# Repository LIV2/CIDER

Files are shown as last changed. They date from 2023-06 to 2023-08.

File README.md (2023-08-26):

# CDTV IDE + RAM
IDE + 11.37 Megabyte Fast RAM + Dual Kickstart flash for the CDTV

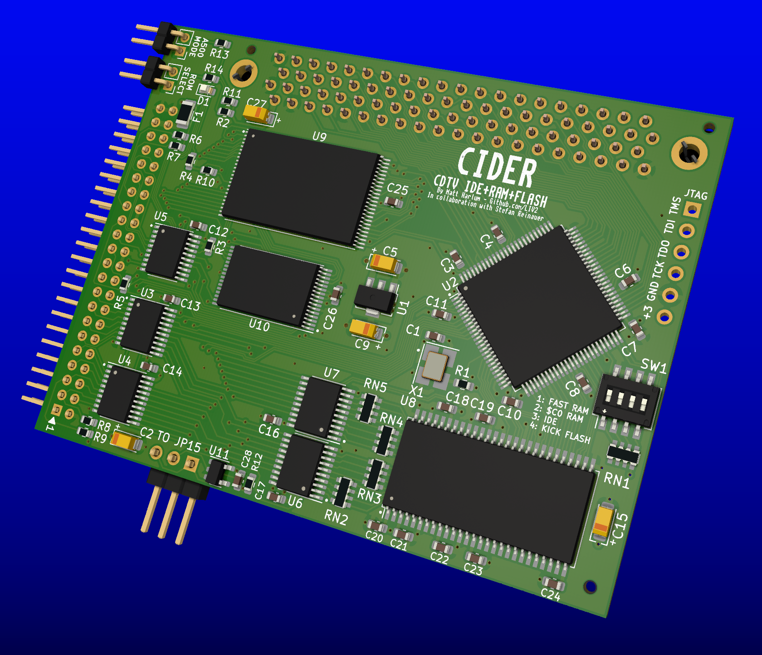
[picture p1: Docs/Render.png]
PCB


## Features

- Plugs in to the Diagnostic port
- Autoboot IDE, Kick 1.3 compatible Open Source driver [lide.device](https://github.com/LIV2/lide.device)
- 11.37MB Fast RAM - 1.5MB $C0/Ranger + 8MB Fast + 1.87 Bonus ($A00000)
- Dual Kickstart Flash ROM with Extended ROM, programmable in-system

## Table of contents
1. [Compatibility](#compatibility)
2. [Quick start](#quick-start)
3. [Switch settings](#switch-settings)
    * [DIP Switches](#dip-switches)
    * [JP15](#jp15)
4. [Programming](#programming)
5. [Software](#software)
6. [Common issues](#common-issues)
7. [Ordering pcbs](#ordering-pcbs)
    * [PCB Order details](#pcb-order-details)
    * [PCB Assembly](#pcb-assembly)
    * [Bill of materials](#bill-of-materials)
8. [Pictures](#pictures)
9. [Acknowledgements](#acknowledgements)
10. [License](#license)

## Compatibility

Compatible with kickstart 1.3 and up.

## Quick start
* Remove the power cord from your CDTV
* Ensure the kick flash switch is turned off before using for the first time, all other dip-switches may be enabled if you wish
* Plug into the diag port in your CDTV
* Connect jumper-wire from CDTV JP15 and "To JP15" header, or remove the jumper from the CDTV's JP15 header
* Boot from the CIDER-IDE-Update.adf [here](https://github.com/LIV2/CIDER-Software/releases) to install the IDE ROM
* Download the software tools from the [CIDER-Software](https://github.com/LIV2/cider-software/releases) release page
* Consult the software [documentation](https://github.com/LIV2/CIDER-Software/blob/main/README.md)

## Switch settings
* A500 Mode: Disables the CDTV extended rom
* ROM Select: Selects the second bank of the Kickstart Flash when closed

### DIP Switches
1. Fast RAM enable
2. Ranger / $C0 RAM enable
3. IDE enable
4. Kick flash enable

### JP15
CIDER needs to disable the CDTV's own extended roms when in A500 mode, or when CIDER's Kick flash is enabled so that it can take over this function  
If you don't have a cable to connect this, you can simply remove the JP15 jumper (but the ext rom will then be disabled even if kick flash is switched off)

## Programming

Program the CPLD using this [jed file](https://github.com/LIV2/CIDER/raw/main/Binary/CIDER.jed) - You can find instructions on how to do that [here](https://linuxjedi.co.uk/2020/12/01/programming-xilinx-jtag-from-a-raspberry-pi/)

IDE ROM can be programmed by booting from the latest CIDER-IDE-Update.adf [here](https://github.com/LIV2/CIDER-Software/releases).

## Software

Various software tools for CIDER are available in the [CIDER-Software](https://github.com/LIV2/CIDER-Software) repository, you can find disk images and .lha files under the Releases section.

## Common issues

* **CDTV doesn't boot from IDE:** The original CDTV bootstrap does not boot from hard disks by default, only the builtin scsi.device, floppy or cdrom.  
To boot from the HDD I recommend making use of the 2.35 Extended rom from [CDTV Land](https://cdtvland.com/os235/)

## Ordering PCBs

Download the latest Gerbers.zip from the latest release listed on the right-hand side of this page.

Also included in the release are the placement and bom files needed for JLCPCB's assembly service

### PCB Order details
This PCB has been designed to JLCPCB's 4-layer capabilities so I recommend ordering from them

* Layers: 4
* Surface finish: ENIG
* Remove Order Number: Specify a location

### PCB Assembly
The release files include the relevant BOM and CPL files for JLCPCB's Assembly service  
You can use the following options:  
* PCBA Type: Economic
* Assembly side: Top side
* Tooling Holes: Added by Customer
* Confirm Parts Placement: Yes (I recommend checking that all ICs have pin 1 in the correct location etc)

### Bill of materials
|References|Qty|Value|Footprint|Link|Notes|
|---|---|-----|---|----|-----|
|CN1|1|CDTV Connector|KEL 8801-080-170S-F| |Contact KEL to order|
|C1,C3,C4,C6,C7,C8,C10,C11-14,C16-26,C28|23|0.1uF Ceramic|0603|[Mouser](https://www.mouser.com/ProductDetail/80-C603C104K5RAC3121)| |
|C2,C5,C27|3|47uF Tantalum|EIA-3216 KEMET A|[Mouser](https://www.mouser.com/ProductDetail/80-T490A476M10ATE1K)| |
|C9,C15|3|10uF Tantalum|EIA-3216 KEMET A|[Mouser](https://www.mouser.com/ProductDetail/581-TAJA106K016R)| |
|R2,R3,R5-12|10|10K|0603|[Mouser](https://www.mouser.com/ProductDetail/279-CRGH0603J10K)| |
|R13,R14|2|1K|0603|[Mouser](https://www.mouser.com/ProductDetail/791-WR06X102JTL)| |
|R1|1|33|0603|[Mouser](https://www.mouser.com/ProductDetail/279-CRG0603F33R)| |
|R4|1|220|0603|[Mouser](https://www.mouser.com/ProductDetail/71-CRCW0603-220-E3)| |
|D1|1|SMD LED|0603|[Mouser](https://www.mouser.com/ProductDetail/710-150060VS75003)| |
|U3-5|3|74HCT245|TSSOP-20|[Mouser](https://www.mouser.com/ProductDetail/595-SN74HCT245PWR)| |
|U6-7|3|74LVC245|TSSOP-20|[Mouser](https://www.mouser.com/ProductDetail/595-SN74LVC245APWR)| |
|U1|1|AZ1117CR-3.3|SOT-89-3|[Mouser](https://www.mouser.com/ProductDetail/621-AZ1117CR-3.3TRG1)| |
|U2|1|XC95144XL-10TQ100|TQFP-100|[Mouser](https://www.mouser.com/ProductDetail/217-5144XL-10TQG100C)|
|U8|1|8Mx16 SDRAM A3V28S40JTP-60|TSOP-II-54|[Mouser](https://www.mouser.com/ProductDetail/155-A3V28S40JTP-60)|Also suitable:</br> MT48LC8M16</br>W9812G6KH|
|U9|1|29F160|TSOP-I-48|[Mouser](https://www.mouser.com/ProductDetail/913-M29F160FB5AN6F2)| |
|U10|1|39SF010|TSOP-I-32|[Mouser](https://www.mouser.com/ProductDetail/804-39SF010A7CWHE)| |
|U11|1|74LVC1G32|SOT-23-5|[Mouser](https://www.mouser.com/ProductDetail/595-SN74LVC1G32DBVR)| |
|X1|1|50MHz Oscillator|3.2x2.5mm|[Mouser](https://www.mouser.com/ProductDetail/520-ECS-2333-500-BNT)| |
|F1|1|Polyfuse 1A trip, 500mA hold|1206|[Mouser](https://www.mouser.com/ProductDetail/576-1206L075/13.2WR)| |
|SW1|1|Omron A6H-4101|A6H-4101|[Mouser](https://www.mouser.com/ProductDetail/653-A6H-4101)| |
|RN1|1|10K|R Array Convex 4x0603|[Mouser](https://www.mouser.com/ProductDetail/667-EXB-V8V103GV)| |
|RN2-5|4|22 Ohm|R Array Convex 4x0603|[Mouser](https://www.mouser.com/ProductDetail/667-EXB-V8N220JV)| |
|J2-J3|2|Header|2.0mm 1x02 Right-angle| | |
|J5|1|Header|2.54mm 1x03 Right-angle| | |

## Pictures
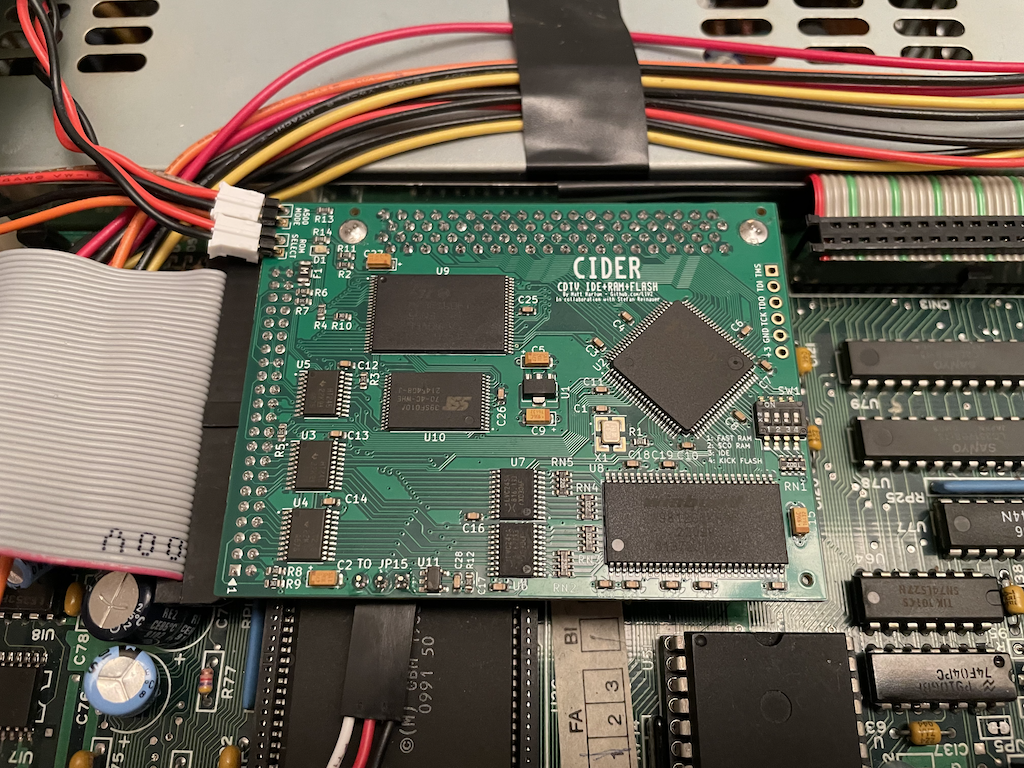
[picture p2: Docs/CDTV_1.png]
CDTV_1

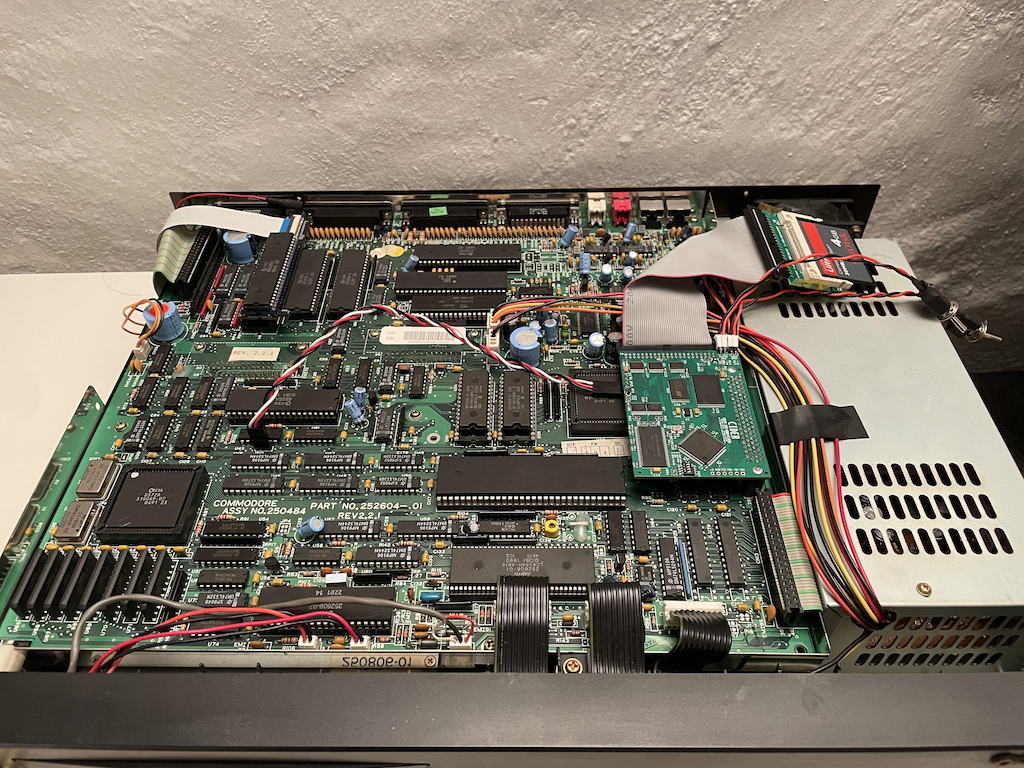
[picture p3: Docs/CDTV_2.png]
CDTV_2


## Acknowledgements

Thanks to [Stefan Reinauer](https://github.com/reinauer) for the idea to make a CDTV expansion, helping me to develop & test this and for sourcing some Connectors!  
The addition of the Kickstart Flash was inspired by [jbilander](https://github.com/jbilander)'s awesome [Spitfire 2000](https://github.com/jbilander/SF2000)  
Thank you to [Eriond](https://github.com/eriond) for providing the 3D Model of the KEL connector! 

## License


CIDER is licensed under the GPL-2.0 only license

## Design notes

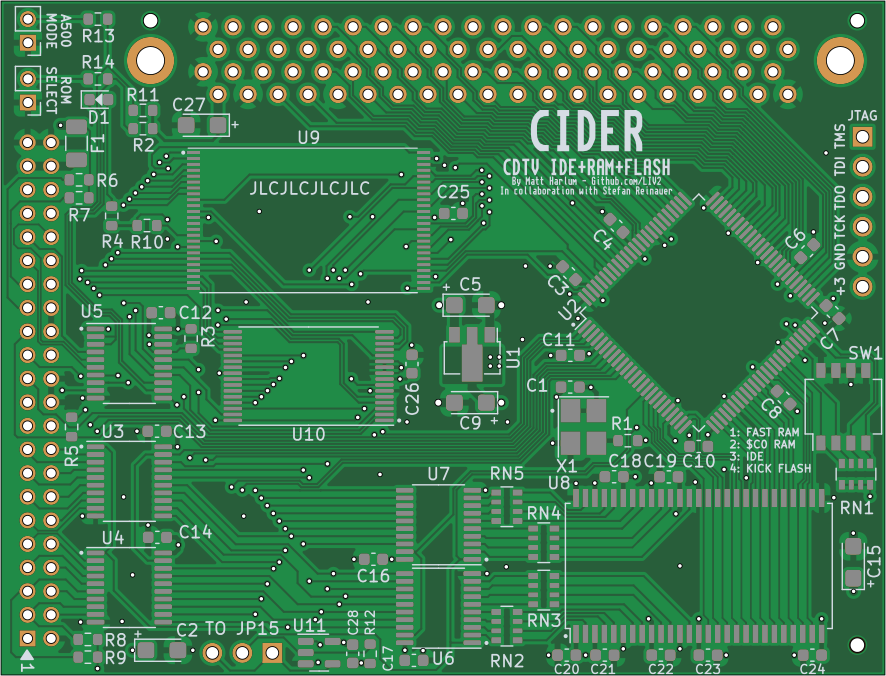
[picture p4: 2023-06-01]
Docs/PCB.png

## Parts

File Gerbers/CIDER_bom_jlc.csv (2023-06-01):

Comment | Designator | Footprint | LCSC Part #
0.1u | C1,C3,C4,C6,C7,C8,C10,C11,C12,C13,C14,C16,C17,C18,C19,C20,C21,C22,C23,C24,C25,C26,C28 | C_0603_1608Metric | C14663
10u | C9,C15 | CP_EIA-3216-18_Kemet-A | C7171
47u | C2,C5,C27 | CP_EIA-3216-18_Kemet-A | C193224
ACT | D1 | LED_0603_1608Metric | C264450
Polyfuse 500mA Hold | F1 | Fuse_1206_3216Metric | C151162
33 | R1 | R_0603_1608Metric | C23140
220 | R4 | R_0603_1608Metric | C22962
1K | R13,R14 | R_0603_1608Metric | C21190
10K | R2,R3,R5,R6,R7,R8,R9,R10,R11,R12 | R_0603_1608Metric | C25804
22 | RN2,RN3,RN4,RN5 | R_Array_Convex_4x0603 | C107373
10K | RN1 | R_Array_Convex_4x0603 | C110924
SW_DIP_x04 | SW1 | SW_DIP_SPSTx04_Slide_Omron_A6H-4101_W6.15mm_P1.27mm | C397291
29F160 | U9 | TSOP-I-48_18.4x12mm_P0.5mm
74HCT245 | U3,U4,U5 | TSSOP-20_4.4x6.5mm_P0.65mm | C6779
74LVC1G32 | U11 | SOT-23-5 | C10096
74LVC245 | U6,U7 | TSSOP-20_4.4x6.5mm_P0.65mm | C7848
AZ1117CR-3.3 | U1 | SOT-89-3 | C460428
MT48LC8M16A2P | U8 | TSOP-II-54_22.2x10.16mm_P0.8mm | C62379
SST39SF010 | U10 | TSOP-I-32_11.8x8mm_P0.5mm
XC95144XL-TQ100 | U2 | TQFP-100_14x14mm_P0.5mm | C45126
50MHz | X1 | Oscillator_SMD_Abracon_ASE-4Pin_3.2x2.5mm_HandSoldering | C46327

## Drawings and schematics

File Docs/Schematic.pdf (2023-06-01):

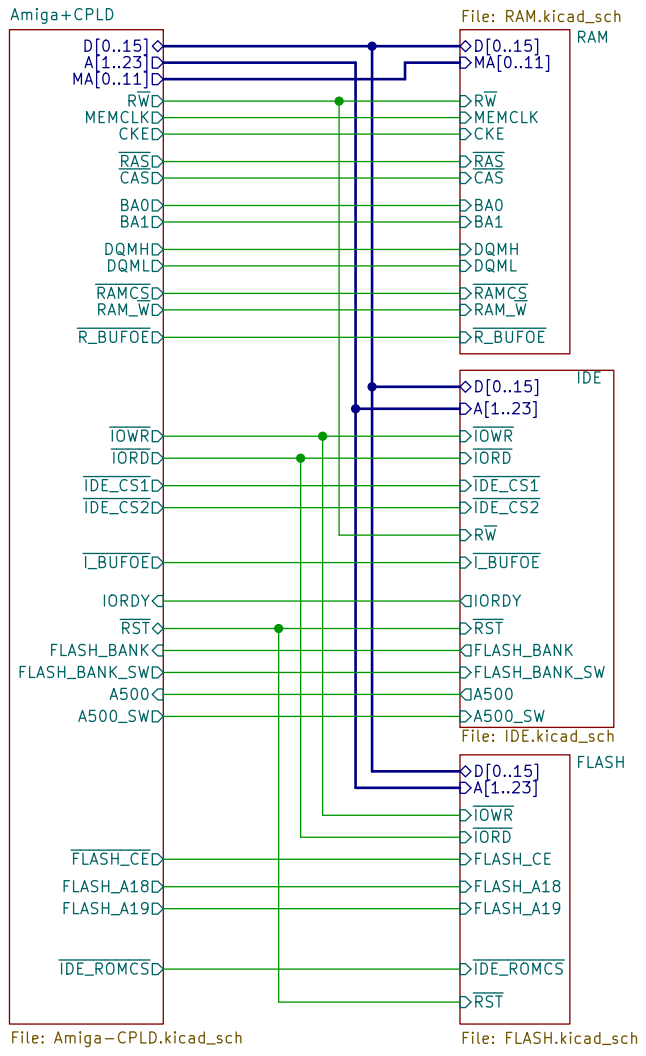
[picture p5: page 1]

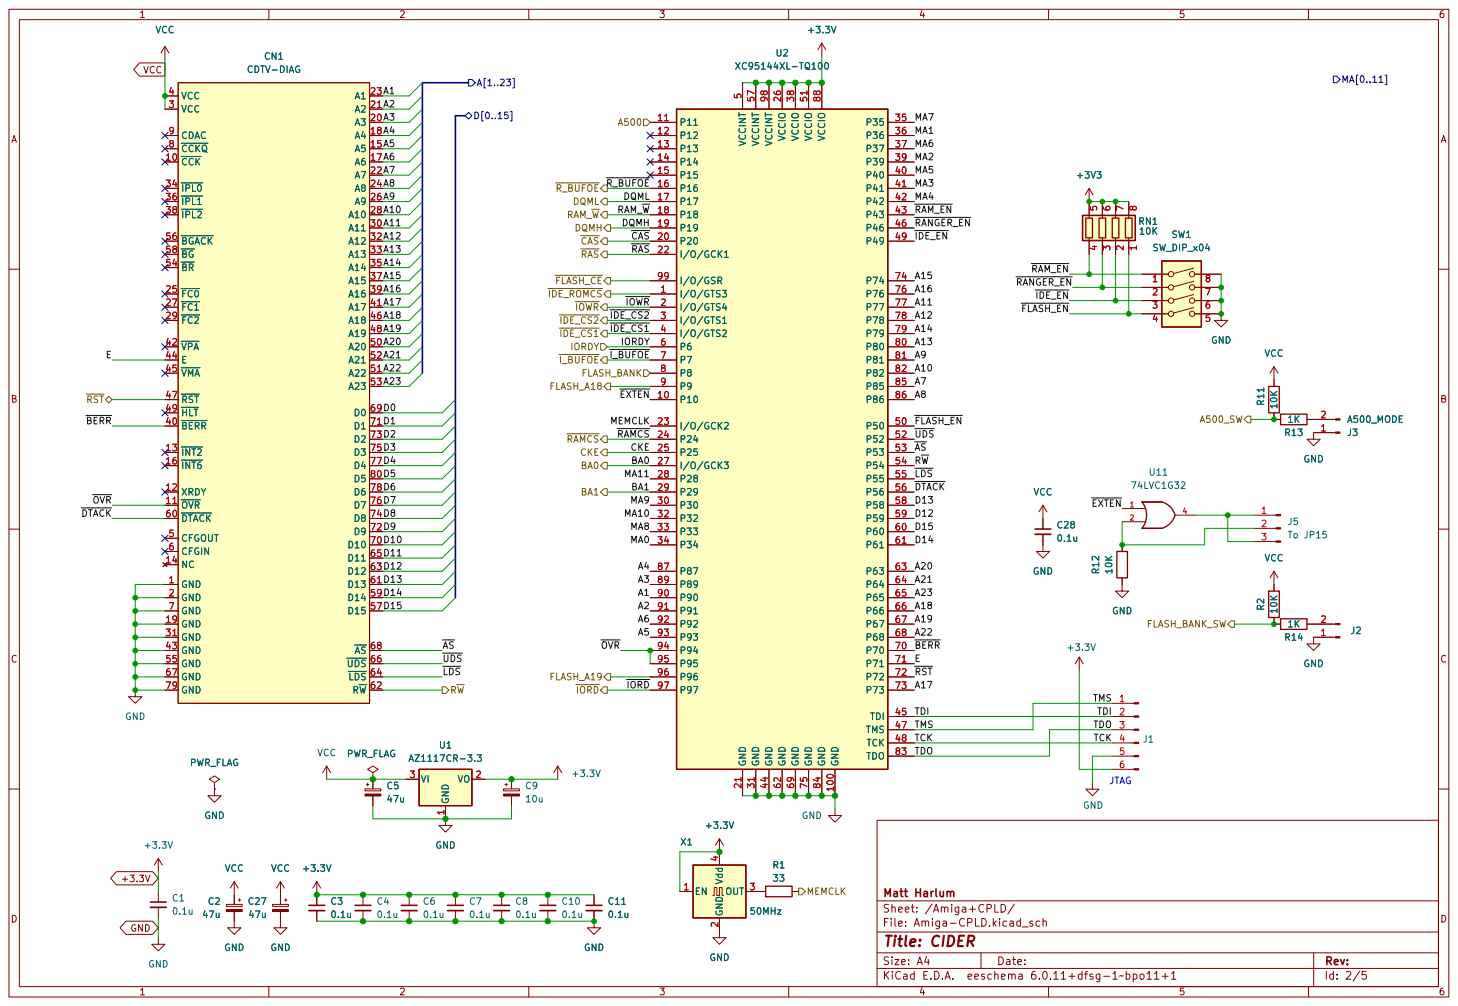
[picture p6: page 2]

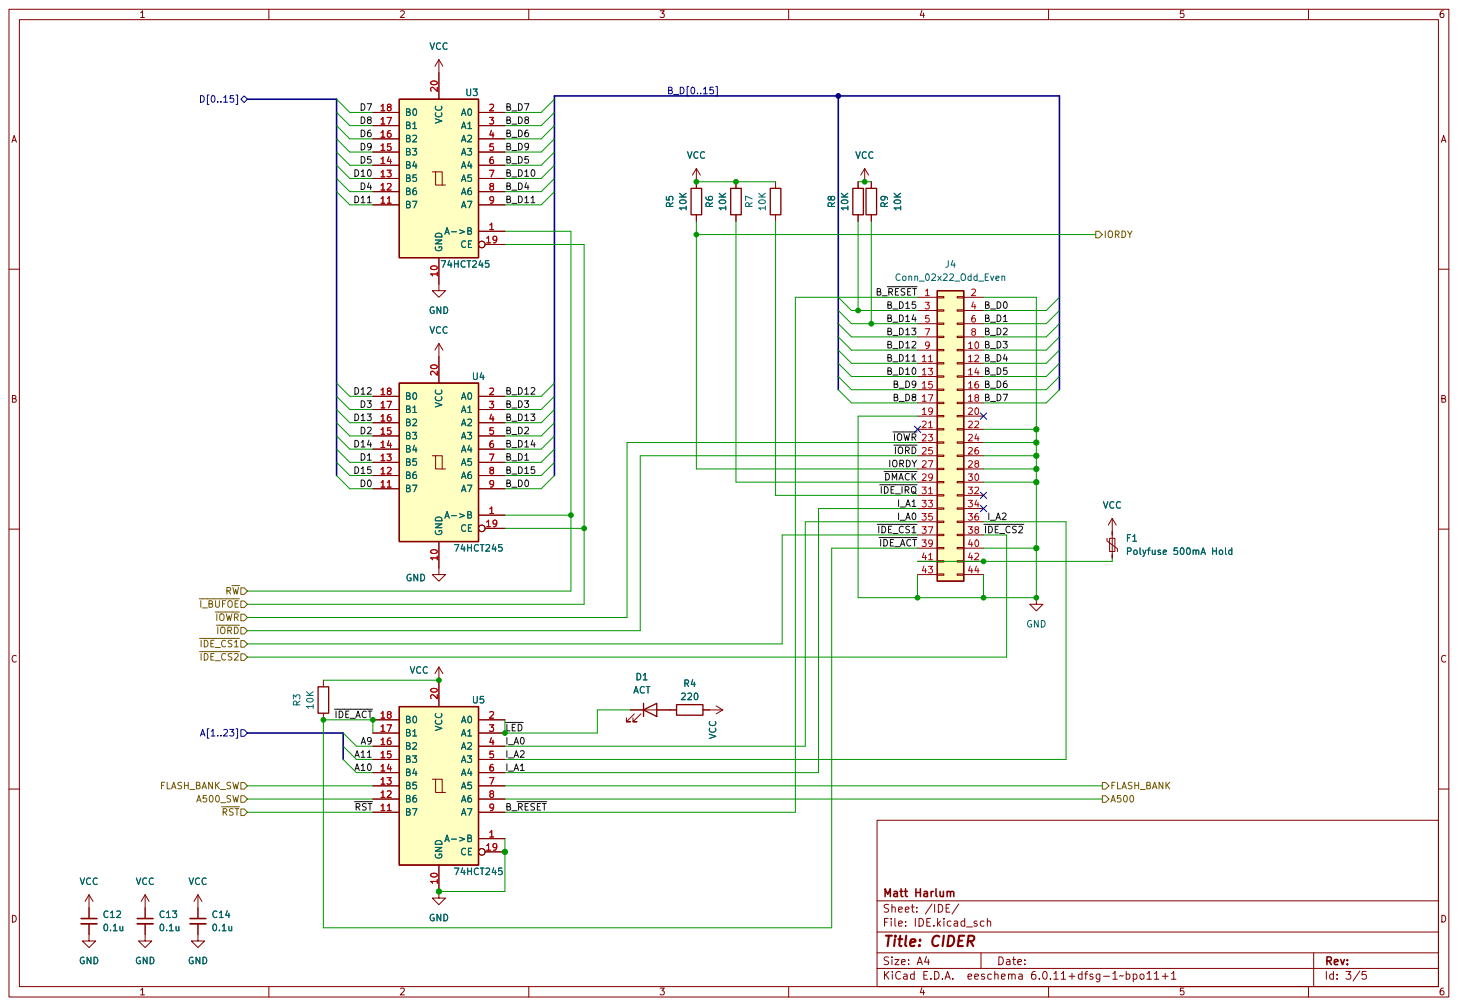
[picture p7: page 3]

~{IORD} 25 | 26
IORDY 27 | 28

74HCT245 A->B | 1 GND 10 B7

31 | | 32
I_A1 33 | | 34
I_A0 35 | | 36
37 | | 38

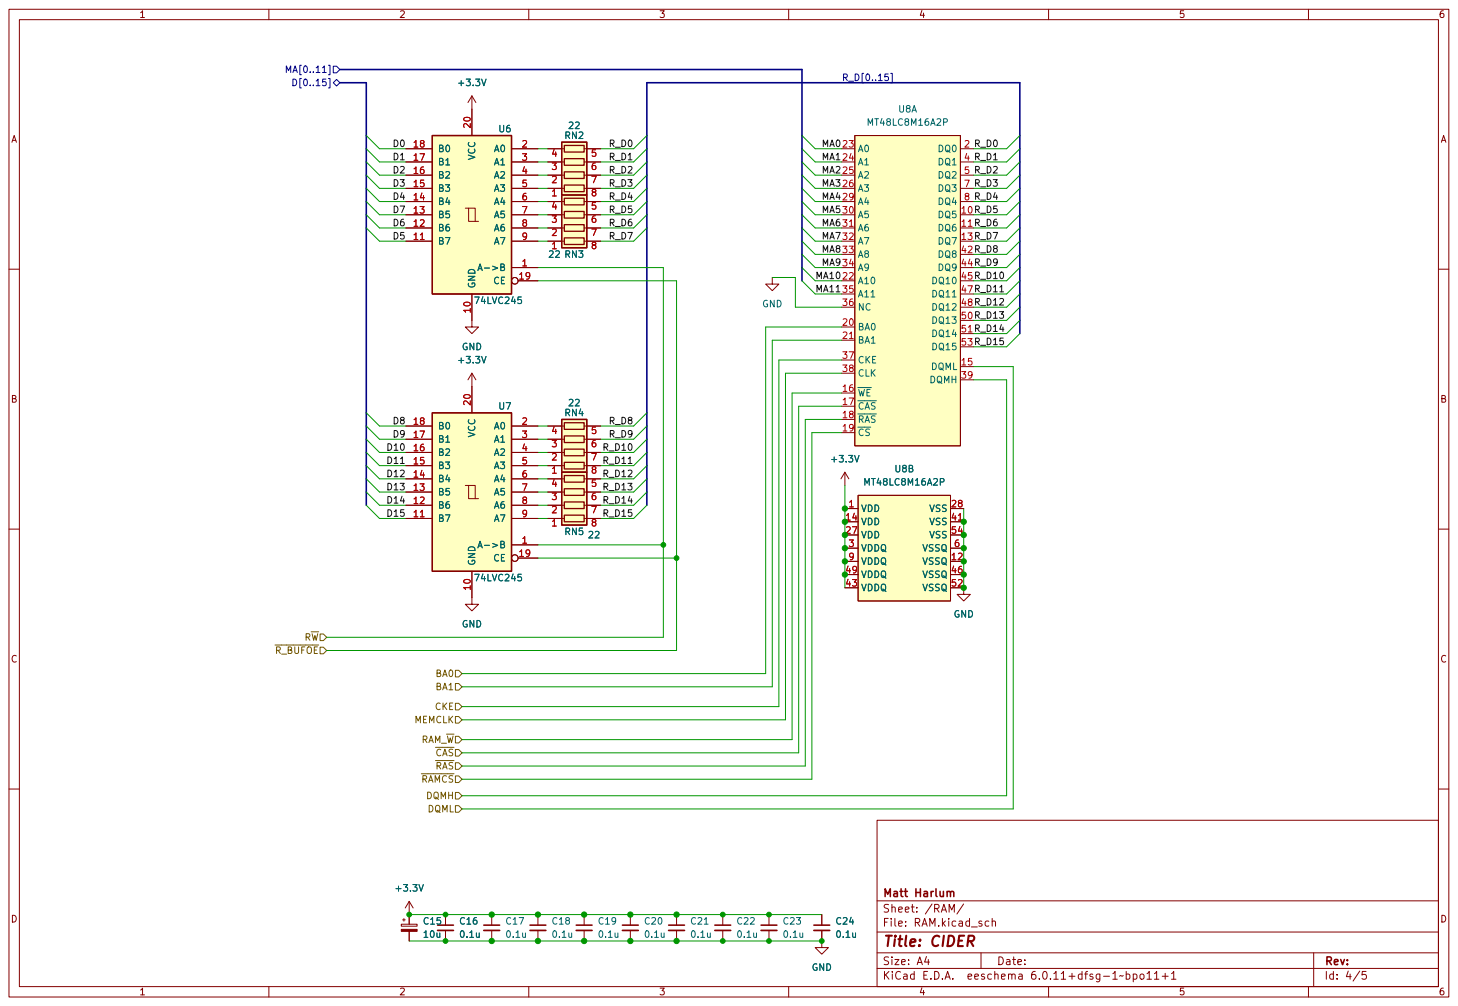
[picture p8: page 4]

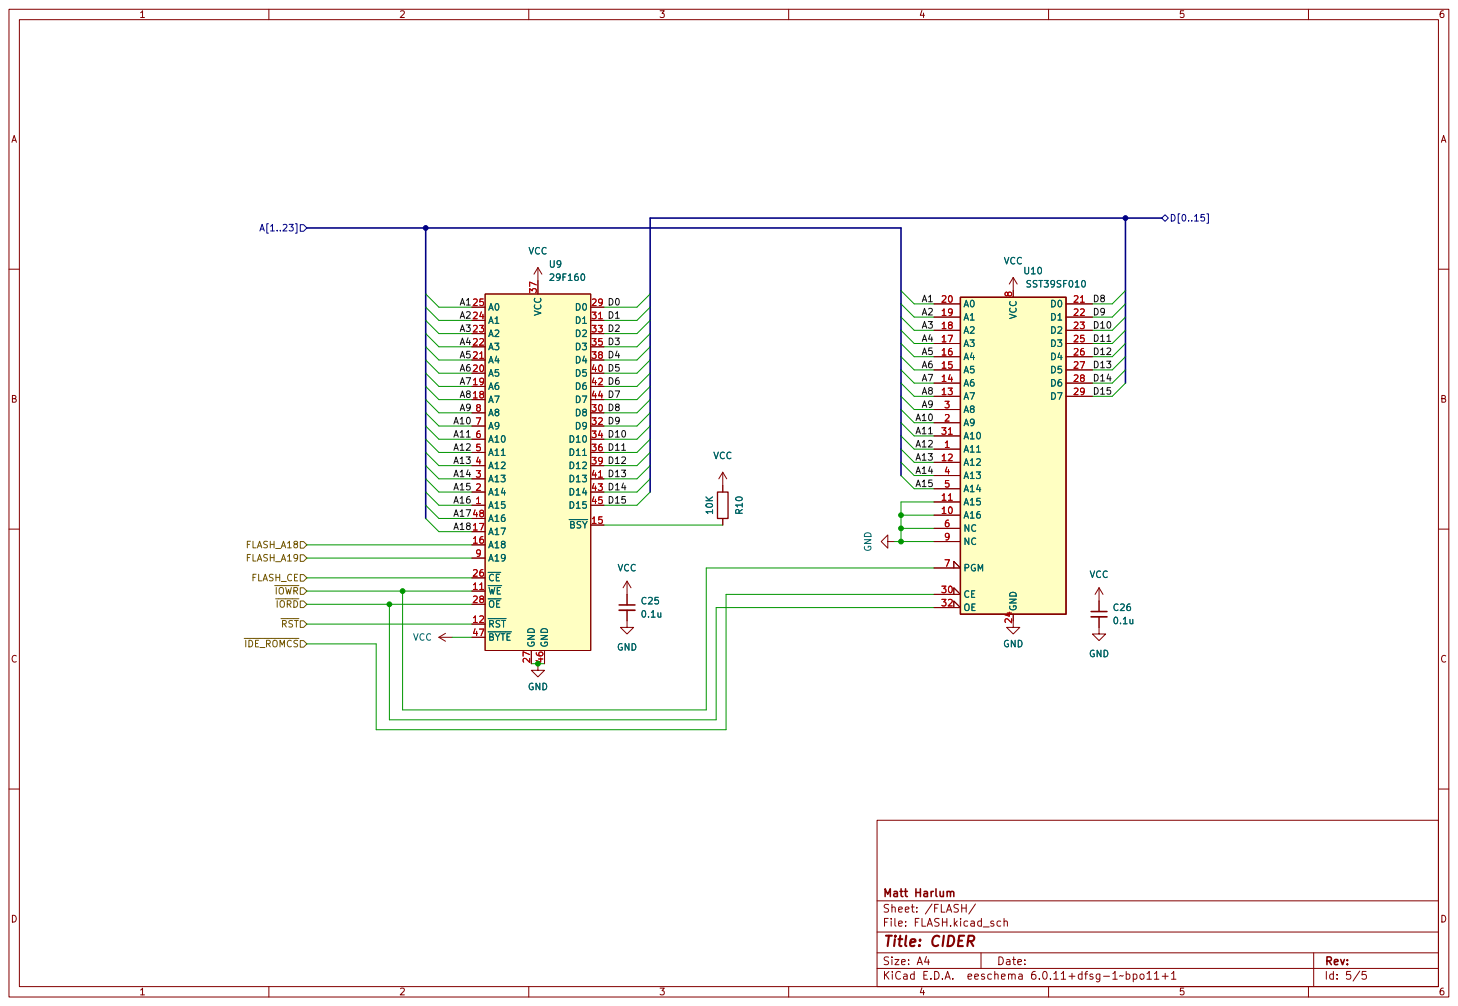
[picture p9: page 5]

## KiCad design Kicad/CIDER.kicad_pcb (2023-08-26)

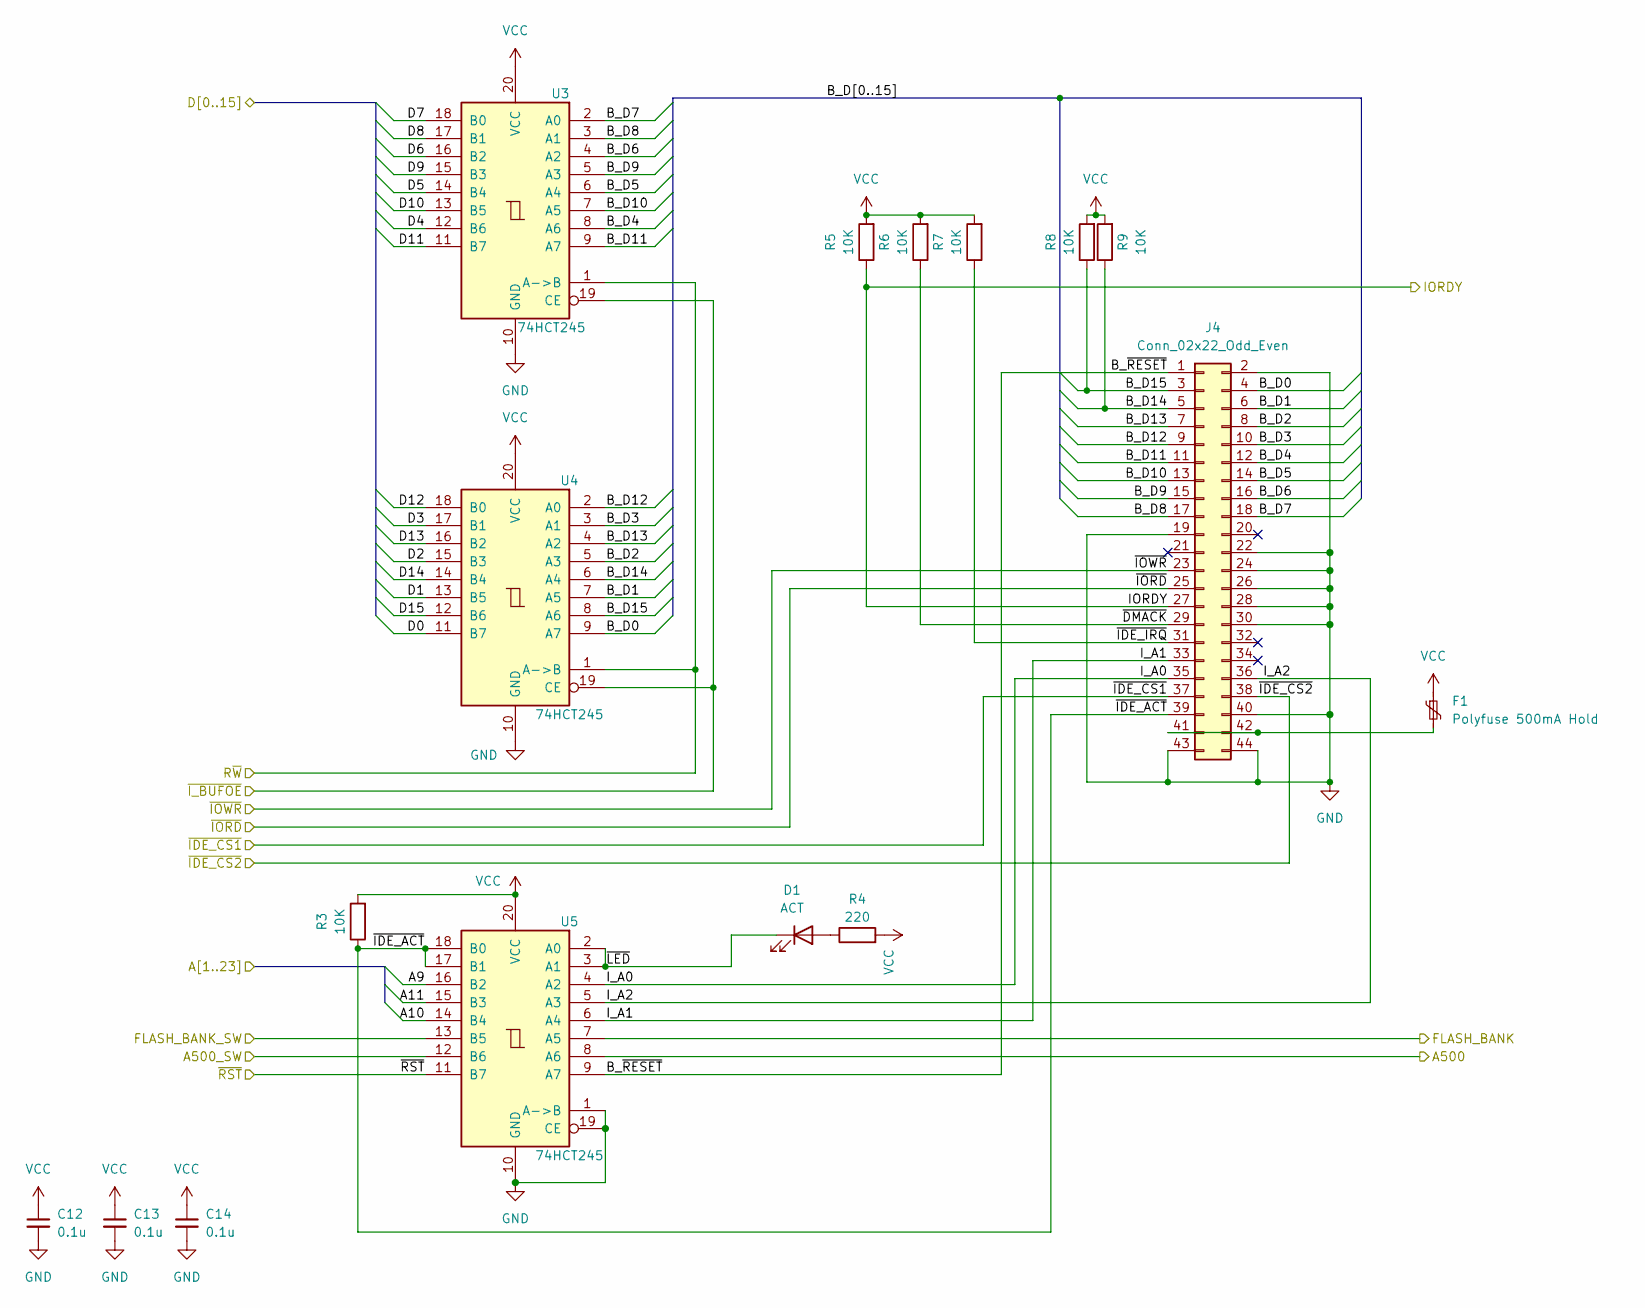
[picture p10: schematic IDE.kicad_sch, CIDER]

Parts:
C12, C13, C14: 0.1u; C_0603_1608Metric; LCSC # C14663
D1: ACT; LED_0603_1608Metric; LCSC # C264450
F1: Polyfuse 500mA Hold; Fuse_1206_3216Metric; LCSC # C151162
J4: Conn_02x22_Odd_Even; PinHeader_2x22_P2.00mm_Vertical
R3, R5, R6, R7, R8, R9: 10K; R_0603_1608Metric; LCSC # C25804
R4: 220; R_0603_1608Metric; LCSC # C22962
U3, U4, U5: 74HCT245; TSSOP-20_4.4x6.5mm_P0.65mm; LCSC # C6779

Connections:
/Amiga+CPLD/A9: U5.16 (B2); also elsewhere on the board
/Amiga+CPLD/A10: U5.14 (B4); also elsewhere on the board
/Amiga+CPLD/A11: U5.15 (B3); also elsewhere on the board
/Amiga+CPLD/A500: U5.8 (A6); also elsewhere on the board
/Amiga+CPLD/A500_SW: U5.12 (B6); also elsewhere on the board
/Amiga+CPLD/D0: U4.11 (B7); also elsewhere on the board
/Amiga+CPLD/D1: U4.13 (B5); also elsewhere on the board
/Amiga+CPLD/D2: U4.15 (B3); also elsewhere on the board
/Amiga+CPLD/D3: U4.17 (B1); also elsewhere on the board
/Amiga+CPLD/D4: U3.12 (B6); also elsewhere on the board
/Amiga+CPLD/D5: U3.14 (B4); also elsewhere on the board
/Amiga+CPLD/D6: U3.16 (B2); also elsewhere on the board
/Amiga+CPLD/D7: U3.18 (B0); also elsewhere on the board
/Amiga+CPLD/D8: U3.17 (B1); also elsewhere on the board
/Amiga+CPLD/D9: U3.15 (B3); also elsewhere on the board
/Amiga+CPLD/D10: U3.13 (B5); also elsewhere on the board
/Amiga+CPLD/D11: U3.11 (B7); also elsewhere on the board
/Amiga+CPLD/D12: U4.18 (B0); also elsewhere on the board
/Amiga+CPLD/D13: U4.16 (B2); also elsewhere on the board
/Amiga+CPLD/D14: U4.14 (B4); also elsewhere on the board
/Amiga+CPLD/D15: U4.12 (B6); also elsewhere on the board
/Amiga+CPLD/FLASH_BANK: U5.7 (A5); also elsewhere on the board
/Amiga+CPLD/FLASH_BANK_SW: U5.13 (B5); also elsewhere on the board
/Amiga+CPLD/IORDY: J4.27, R5.1; also elsewhere on the board
/Amiga+CPLD/R~W: U3.1 (A->B), U4.1 (A->B); also elsewhere on the board
/Amiga+CPLD/~IDE_CS1: J4.37; also elsewhere on the board
/Amiga+CPLD/~IDE_CS2: J4.38; also elsewhere on the board
/Amiga+CPLD/~IORD: J4.25; also elsewhere on the board
/Amiga+CPLD/~IOWR: J4.23; also elsewhere on the board
/Amiga+CPLD/~I_BUFOE: U3.19 (CE), U4.19 (CE); also elsewhere on the board
/Amiga+CPLD/~RST: U5.11 (B7); also elsewhere on the board
/IDE/B_D0: J4.4, U4.9 (A7)
/IDE/B_D1: J4.6, U4.7 (A5)
/IDE/B_D2: J4.8, U4.5 (A3)
/IDE/B_D3: J4.10, U4.3 (A1)
/IDE/B_D4: J4.12, U3.8 (A6)
/IDE/B_D5: J4.14, U3.6 (A4)
/IDE/B_D6: J4.16, U3.4 (A2)
/IDE/B_D7: J4.18, U3.2 (A0)
/IDE/B_D8: J4.17, U3.3 (A1)
/IDE/B_D9: J4.15, U3.5 (A3)
/IDE/B_D10: J4.13, U3.7 (A5)
/IDE/B_D11: J4.11, U3.9 (A7)
/IDE/B_D12: J4.9, U4.2 (A0)
/IDE/B_D13: J4.7, U4.4 (A2)
/IDE/B_D14: J4.5, R9.1, U4.6 (A4)
/IDE/B_D15: J4.3, R8.1, U4.8 (A6)
/IDE/B_~RESET: J4.1, U5.9 (A7)
/IDE/I_A0: J4.35, U5.4 (A2)
/IDE/I_A1: J4.33, U5.6 (A4)
/IDE/I_A2: J4.36, U5.5 (A3)
/IDE/~DMACK: J4.29, R6.1
/IDE/~IDE_ACT: J4.39, R3.1, U5.17 (B1), U5.18 (B0)
/IDE/~IDE_IRQ: J4.31, R7.1
/IDE/~LED: D1.1 (K), U5.2 (A0), U5.3 (A1)
GND: C12.2, C13.2, C14.2, J4.2, J4.19, J4.22, J4.24, J4.26, J4.28, J4.30, J4.40, J4.43, J4.44, U3.10 (GND), U4.10 (GND), U5.1 (A->B), U5.10 (GND), U5.19 (CE); also elsewhere on the board
unnamed: D1.2 (A), R4.1
unnamed: F1.2, J4.41, J4.42
VCC: C12.1, C13.1, C14.1, F1.1, R3.2, R4.2, R5.2, R6.2, R7.2, R8.2, R9.2, U3.20 (VCC), U4.20 (VCC), U5.20 (VCC); also elsewhere on the board

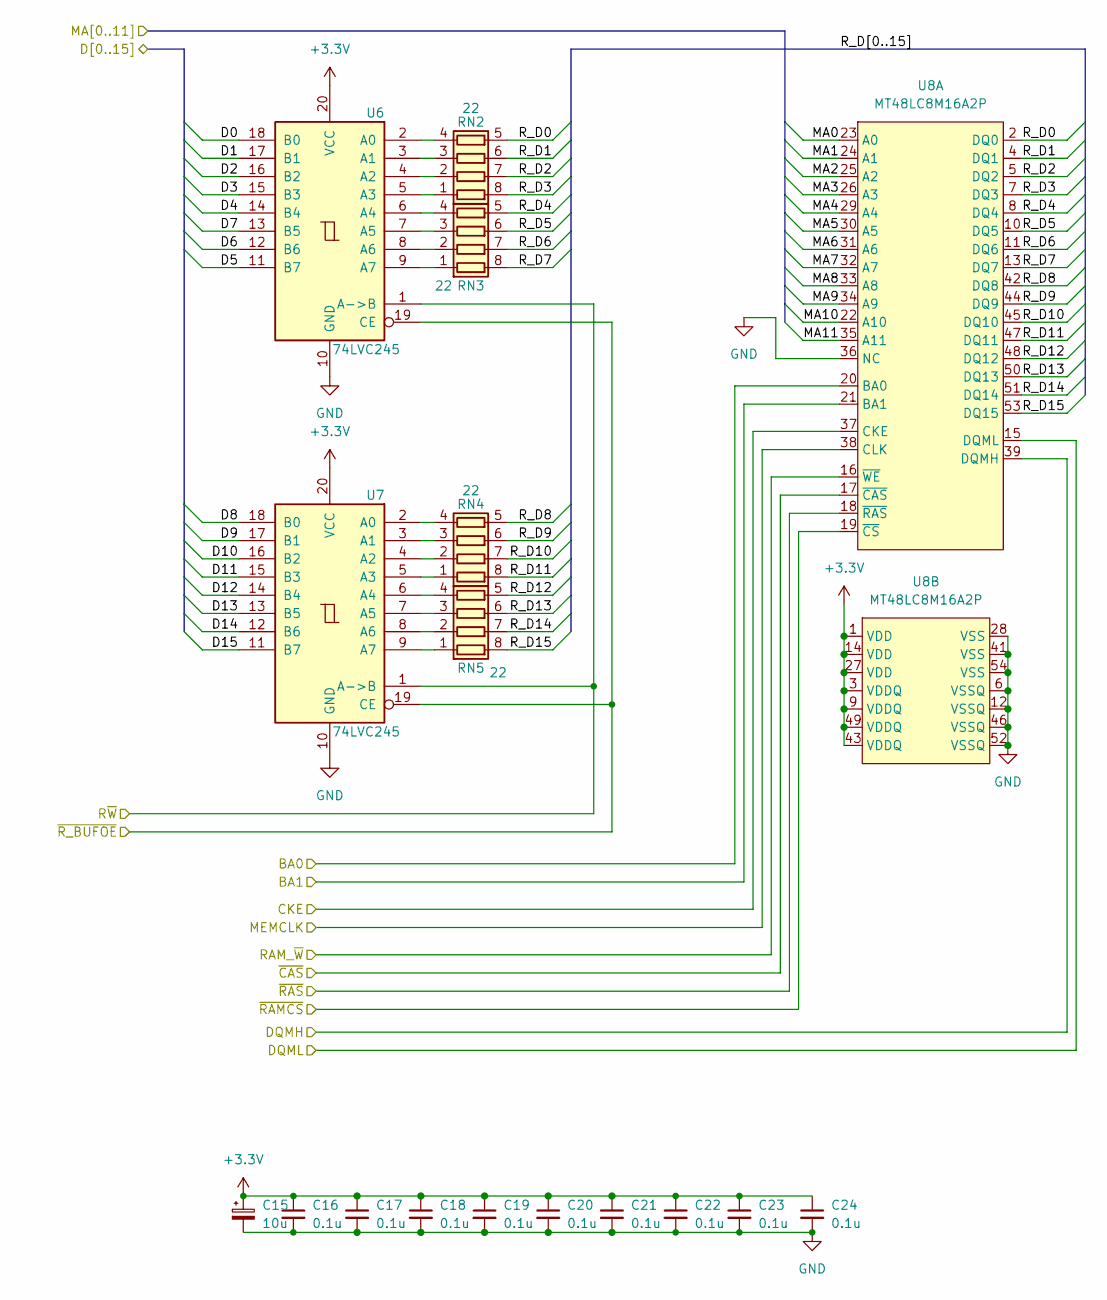
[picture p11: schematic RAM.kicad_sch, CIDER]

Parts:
C15: 10u; CP_EIA-3216-18_Kemet-A; LCSC # C7171
C16, C17, C18, C19, C20, C21, C22, C23, C24: 0.1u; C_0603_1608Metric; LCSC # C14663
RN2, RN3, RN4, RN5: 22; R_Array_Convex_4x0603; LCSC # C107373
U6, U7: 74LVC245; TSSOP-20_4.4x6.5mm_P0.65mm; LCSC # C7848
U8: MT48LC8M16A2P; TSOP-II-54_22.2x10.16mm_P0.8mm; LCSC # C62379

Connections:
/Amiga+CPLD/BA0: U8.20 (BA0); also elsewhere on the board
/Amiga+CPLD/BA1: U8.21 (BA1); also elsewhere on the board
/Amiga+CPLD/CKE: U8.37 (CKE); also elsewhere on the board
/Amiga+CPLD/D0: U6.18 (B0); also elsewhere on the board
/Amiga+CPLD/D1: U6.17 (B1); also elsewhere on the board
/Amiga+CPLD/D2: U6.16 (B2); also elsewhere on the board
/Amiga+CPLD/D3: U6.15 (B3); also elsewhere on the board
/Amiga+CPLD/D4: U6.14 (B4); also elsewhere on the board
/Amiga+CPLD/D5: U6.11 (B7); also elsewhere on the board
/Amiga+CPLD/D6: U6.12 (B6); also elsewhere on the board
/Amiga+CPLD/D7: U6.13 (B5); also elsewhere on the board
/Amiga+CPLD/D8: U7.18 (B0); also elsewhere on the board
/Amiga+CPLD/D9: U7.17 (B1); also elsewhere on the board
/Amiga+CPLD/D10: U7.16 (B2); also elsewhere on the board
/Amiga+CPLD/D11: U7.15 (B3); also elsewhere on the board
/Amiga+CPLD/D12: U7.14 (B4); also elsewhere on the board
/Amiga+CPLD/D13: U7.13 (B5); also elsewhere on the board
/Amiga+CPLD/D14: U7.12 (B6); also elsewhere on the board
/Amiga+CPLD/D15: U7.11 (B7); also elsewhere on the board
/Amiga+CPLD/DQMH: U8.39 (DQMH); also elsewhere on the board
/Amiga+CPLD/DQML: U8.15 (DQML); also elsewhere on the board
/Amiga+CPLD/MA0: U8.23 (A0); also elsewhere on the board
/Amiga+CPLD/MA1: U8.24 (A1); also elsewhere on the board
/Amiga+CPLD/MA2: U8.25 (A2); also elsewhere on the board
/Amiga+CPLD/MA3: U8.26 (A3); also elsewhere on the board
/Amiga+CPLD/MA4: U8.29 (A4); also elsewhere on the board
/Amiga+CPLD/MA5: U8.30 (A5); also elsewhere on the board
/Amiga+CPLD/MA6: U8.31 (A6); also elsewhere on the board
/Amiga+CPLD/MA7: U8.32 (A7); also elsewhere on the board
/Amiga+CPLD/MA8: U8.33 (A8); also elsewhere on the board
/Amiga+CPLD/MA9: U8.34 (A9); also elsewhere on the board
/Amiga+CPLD/MA10: U8.22 (A10); also elsewhere on the board
/Amiga+CPLD/MA11: U8.35 (A11); also elsewhere on the board
/Amiga+CPLD/MEMCLK: U8.38 (CLK); also elsewhere on the board
/Amiga+CPLD/RAM_~W: U8.16 (~WE); also elsewhere on the board
/Amiga+CPLD/R~W: U6.1 (A->B), U7.1 (A->B); also elsewhere on the board
/Amiga+CPLD/~CAS: U8.17 (~CAS); also elsewhere on the board
/Amiga+CPLD/~RAMCS: U8.19 (~CS); also elsewhere on the board
/Amiga+CPLD/~RAS: U8.18 (~RAS); also elsewhere on the board
/Amiga+CPLD/~R_BUFOE: U6.19 (CE), U7.19 (CE); also elsewhere on the board
/RAM/R_D0: RN2.5 (R4.2), U8.2 (DQ0)
/RAM/R_D1: RN2.6 (R3.2), U8.4 (DQ1)
/RAM/R_D2: RN2.7 (R2.2), U8.5 (DQ2)
/RAM/R_D3: RN2.8 (R1.2), U8.7 (DQ3)
/RAM/R_D4: RN3.5 (R4.2), U8.8 (DQ4)
/RAM/R_D5: RN3.6 (R3.2), U8.10 (DQ5)
/RAM/R_D6: RN3.7 (R2.2), U8.11 (DQ6)
/RAM/R_D7: RN3.8 (R1.2), U8.13 (DQ7)
/RAM/R_D8: RN4.5 (R4.2), U8.42 (DQ8)
/RAM/R_D9: RN4.6 (R3.2), U8.44 (DQ9)
/RAM/R_D10: RN4.7 (R2.2), U8.45 (DQ10)
/RAM/R_D11: RN4.8 (R1.2), U8.47 (DQ11)
/RAM/R_D12: RN5.5 (R4.2), U8.48 (DQ12)
/RAM/R_D13: RN5.6 (R3.2), U8.50 (DQ13)
/RAM/R_D14: RN5.7 (R2.2), U8.51 (DQ14)
/RAM/R_D15: RN5.8 (R1.2), U8.53 (DQ15)
GND: C15.2, C16.2, C17.2, C18.2, C19.2, C20.2, C21.2, C22.2, C23.2, C24.2, U6.10 (GND), U7.10 (GND), U8.6 (VSSQ), U8.12 (VSSQ), U8.28 (VSS), U8.36 (NC), U8.41 (VSS), U8.46 (VSSQ), U8.52 (VSSQ), U8.54 (VSS); also elsewhere on the board
unnamed: RN2.1 (R1.1), U6.5 (A3)
unnamed: RN2.2 (R2.1), U6.4 (A2)
unnamed: RN2.3 (R3.1), U6.3 (A1)
unnamed: RN2.4 (R4.1), U6.2 (A0)
unnamed: RN3.1 (R1.1), U6.9 (A7)
unnamed: RN3.2 (R2.1), U6.8 (A6)
unnamed: RN3.3 (R3.1), U6.7 (A5)
unnamed: RN3.4 (R4.1), U6.6 (A4)
unnamed: RN4.1 (R1.1), U7.5 (A3)
unnamed: RN4.2 (R2.1), U7.4 (A2)
unnamed: RN4.3 (R3.1), U7.3 (A1)
unnamed: RN4.4 (R4.1), U7.2 (A0)
unnamed: RN5.1 (R1.1), U7.9 (A7)
unnamed: RN5.2 (R2.1), U7.8 (A6)
unnamed: RN5.3 (R3.1), U7.7 (A5)
unnamed: RN5.4 (R4.1), U7.6 (A4)

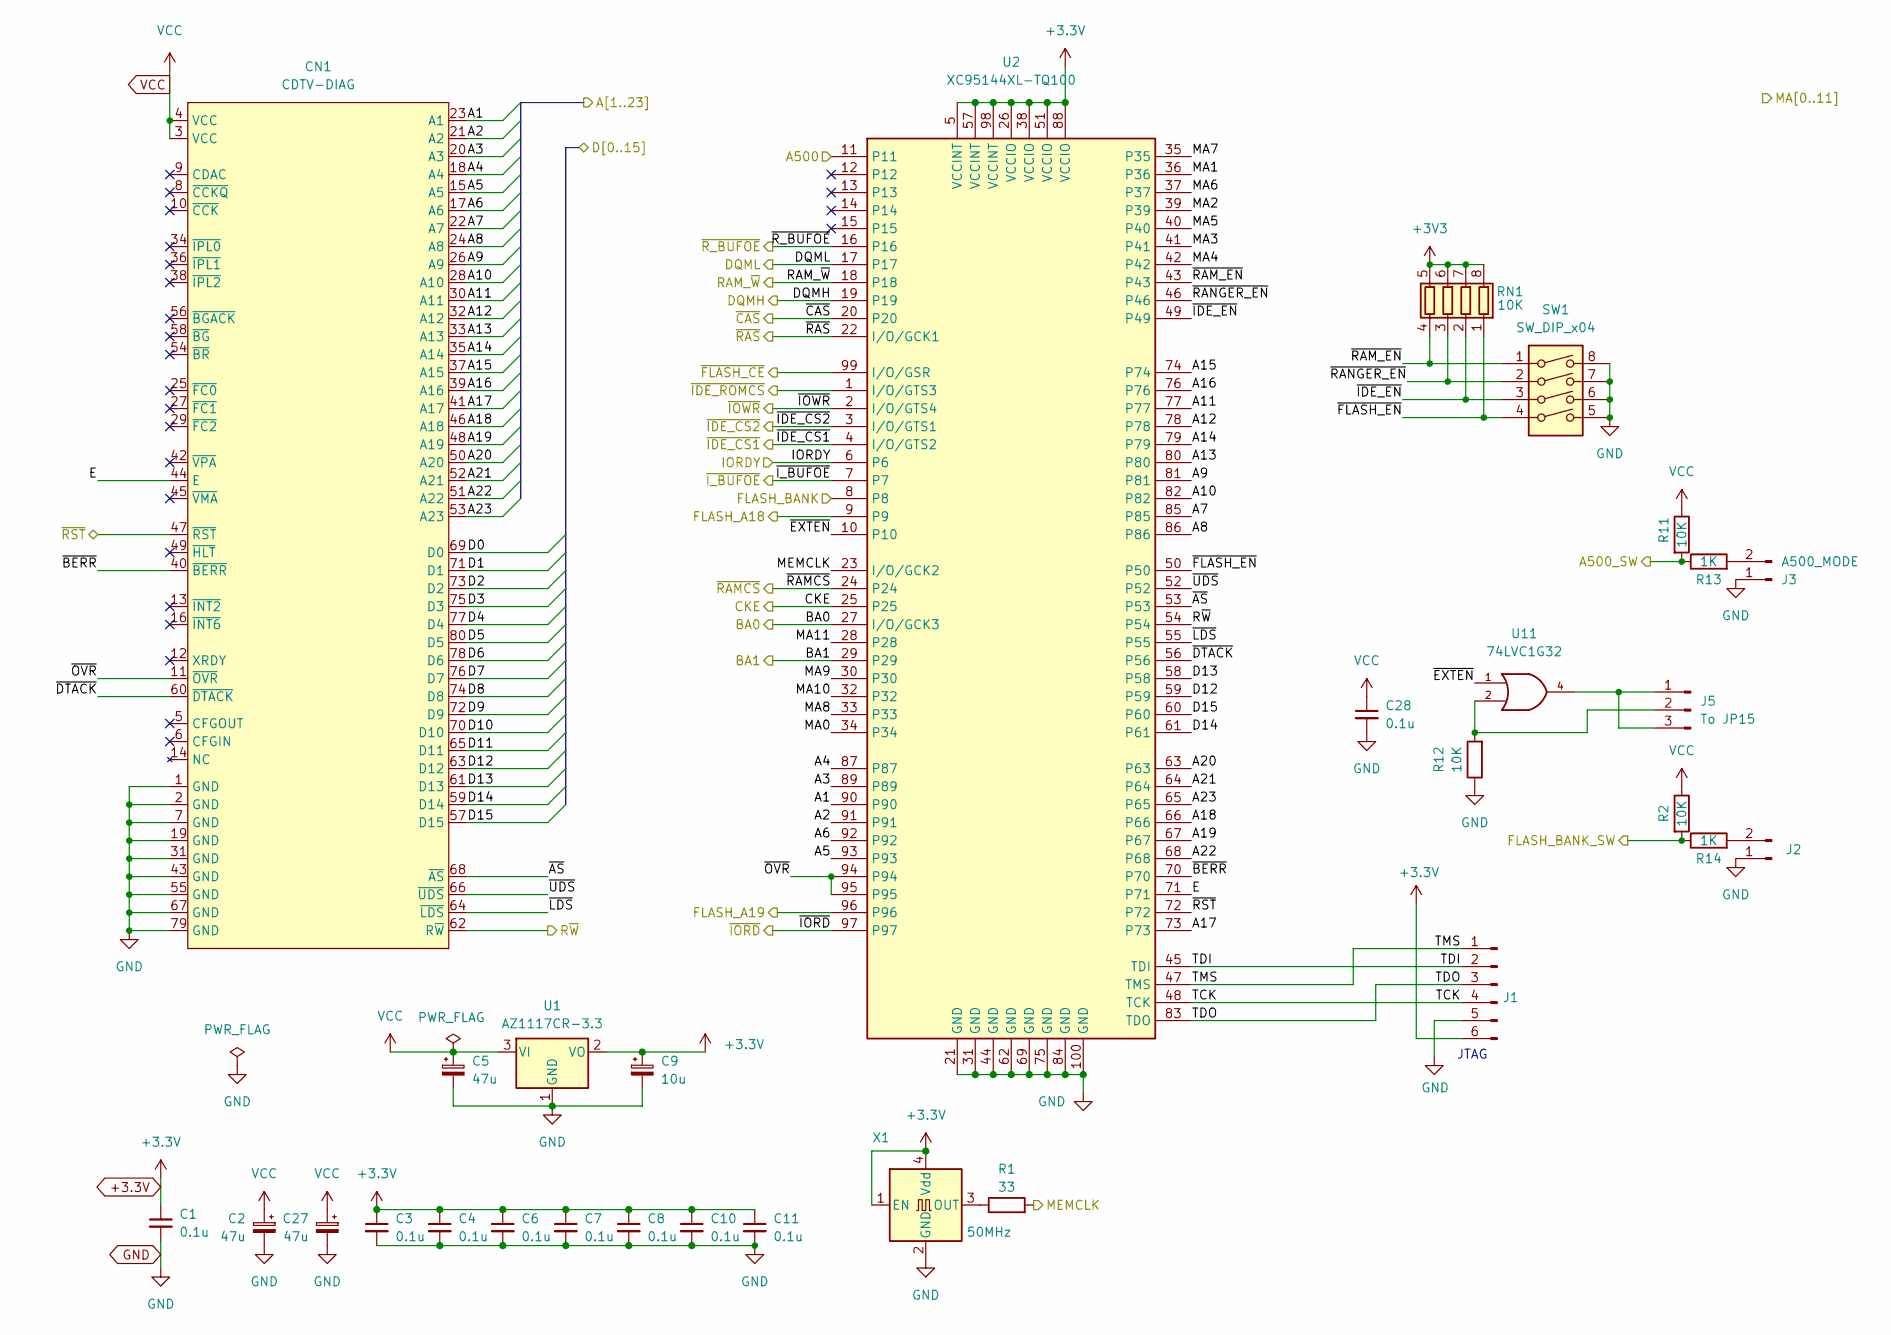
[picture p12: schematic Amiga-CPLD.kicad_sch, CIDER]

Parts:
C1, C3, C4, C6, C7, C8, C10, C11, C28: 0.1u; C_0603_1608Metric; LCSC # C14663
C2, C5, C27: 47u; CP_EIA-3216-18_Kemet-A; LCSC # C193224
C9: 10u; CP_EIA-3216-18_Kemet-A; LCSC # C7171
CN1: CDTV-DIAG; KEL-8800-080-170S
J1: JTAG; PinHeader_1x06_P2.54mm_Vertical
J2: LED; PinHeader_1x02_P2.00mm_Vertical
J3: A500_MODE; PinHeader_1x02_P2.00mm_Vertical
J5: To JP15; PinHeader_1x03_P2.54mm_Horizontal
R1: 33; R_0603_1608Metric; LCSC # C23140
R2, R11, R12: 10K; R_0603_1608Metric; LCSC # C25804
R13, R14: 1K; R_0603_1608Metric; LCSC # C21190
RN1: 10K; R_Array_Convex_4x0603; LCSC # C110924
SW1: SW_DIP_x04; SW_DIP_SPSTx04_Slide_Omron_A6H-4101_W6.15mm_P1.27mm; LCSC # C397291
U1: AZ1117CR-3.3; SOT-89-3; LCSC # C460428
U2: XC95144XL-TQ100; TQFP-100_14x14mm_P0.5mm; LCSC # C45126
U11: 74LVC1G32; SOT-23-5; LCSC # C10096
X1: 50MHz; Oscillator_SMD_Abracon_ASE-4Pin_3.2x2.5mm_HandSoldering; LCSC # C46327

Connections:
/Amiga+CPLD/A1: CN1.23 (A1), U2.90; also elsewhere on the board
/Amiga+CPLD/A2: CN1.21 (A2), U2.91; also elsewhere on the board
/Amiga+CPLD/A3: CN1.20 (A3), U2.89; also elsewhere on the board
/Amiga+CPLD/A4: CN1.18 (A4), U2.87; also elsewhere on the board
/Amiga+CPLD/A5: CN1.15 (A5), U2.93; also elsewhere on the board
/Amiga+CPLD/A6: CN1.17 (A6), U2.92; also elsewhere on the board
/Amiga+CPLD/A7: CN1.22 (A7), U2.85; also elsewhere on the board
/Amiga+CPLD/A8: CN1.24 (A8), U2.86; also elsewhere on the board
/Amiga+CPLD/A9: CN1.26 (A9), U2.81; also elsewhere on the board
/Amiga+CPLD/A10: CN1.28 (A10), U2.82; also elsewhere on the board
/Amiga+CPLD/A11: CN1.30 (A11), U2.77; also elsewhere on the board
/Amiga+CPLD/A12: CN1.32 (A12), U2.78; also elsewhere on the board
/Amiga+CPLD/A13: CN1.33 (A13), U2.80; also elsewhere on the board
/Amiga+CPLD/A14: CN1.35 (A14), U2.79; also elsewhere on the board
/Amiga+CPLD/A15: CN1.37 (A15), U2.74; also elsewhere on the board
/Amiga+CPLD/A16: CN1.39 (A16), U2.76; also elsewhere on the board
/Amiga+CPLD/A17: CN1.41 (A17), U2.73; also elsewhere on the board
/Amiga+CPLD/A18: CN1.46 (A18), U2.66; also elsewhere on the board
/Amiga+CPLD/A19: CN1.48 (A19), U2.67
/Amiga+CPLD/A20: CN1.50 (A20), U2.63
/Amiga+CPLD/A21: CN1.52 (A21), U2.64
/Amiga+CPLD/A22: CN1.51 (A22), U2.68
/Amiga+CPLD/A23: CN1.53 (A23), U2.65
/Amiga+CPLD/A500: U2.11; also elsewhere on the board
/Amiga+CPLD/A500_SW: R11.2, R13.1; also elsewhere on the board
/Amiga+CPLD/BA0: U2.27 (I/O/GCK3); also elsewhere on the board
/Amiga+CPLD/BA1: U2.29; also elsewhere on the board
/Amiga+CPLD/CKE: U2.25; also elsewhere on the board
/Amiga+CPLD/D0: CN1.69 (D0); also elsewhere on the board
/Amiga+CPLD/D1: CN1.71 (D1); also elsewhere on the board
/Amiga+CPLD/D2: CN1.73 (D2); also elsewhere on the board
/Amiga+CPLD/D3: CN1.75 (D3); also elsewhere on the board
/Amiga+CPLD/D4: CN1.77 (D4); also elsewhere on the board
/Amiga+CPLD/D5: CN1.80 (D5); also elsewhere on the board
/Amiga+CPLD/D6: CN1.78 (D6); also elsewhere on the board
/Amiga+CPLD/D7: CN1.76 (D7); also elsewhere on the board
/Amiga+CPLD/D8: CN1.74 (D8); also elsewhere on the board
/Amiga+CPLD/D9: CN1.72 (D9); also elsewhere on the board
/Amiga+CPLD/D10: CN1.70 (D10); also elsewhere on the board
/Amiga+CPLD/D11: CN1.65 (D11); also elsewhere on the board
/Amiga+CPLD/D12: CN1.63 (D12), U2.59; also elsewhere on the board
/Amiga+CPLD/D13: CN1.61 (D13), U2.58; also elsewhere on the board
/Amiga+CPLD/D14: CN1.59 (D14), U2.61; also elsewhere on the board
/Amiga+CPLD/D15: CN1.57 (D15), U2.60; also elsewhere on the board
/Amiga+CPLD/DQMH: U2.19; also elsewhere on the board
/Amiga+CPLD/DQML: U2.17; also elsewhere on the board
/Amiga+CPLD/E: CN1.44 (E), U2.71
/Amiga+CPLD/FLASH_A18: U2.9; also elsewhere on the board
/Amiga+CPLD/FLASH_A19: U2.96; also elsewhere on the board
/Amiga+CPLD/FLASH_BANK: U2.8; also elsewhere on the board
/Amiga+CPLD/FLASH_BANK_SW: R2.2, R14.1; also elsewhere on the board
/Amiga+CPLD/IORDY: U2.6; also elsewhere on the board
/Amiga+CPLD/MA0: U2.34; also elsewhere on the board
/Amiga+CPLD/MA1: U2.36; also elsewhere on the board
/Amiga+CPLD/MA2: U2.39; also elsewhere on the board
/Amiga+CPLD/MA3: U2.41; also elsewhere on the board
/Amiga+CPLD/MA4: U2.42; also elsewhere on the board
/Amiga+CPLD/MA5: U2.40; also elsewhere on the board
/Amiga+CPLD/MA6: U2.37; also elsewhere on the board
/Amiga+CPLD/MA7: U2.35; also elsewhere on the board
/Amiga+CPLD/MA8: U2.33; also elsewhere on the board
/Amiga+CPLD/MA9: U2.30; also elsewhere on the board
/Amiga+CPLD/MA10: U2.32; also elsewhere on the board
/Amiga+CPLD/MA11: U2.28; also elsewhere on the board
/Amiga+CPLD/MEMCLK: R1.2, U2.23 (I/O/GCK2); also elsewhere on the board
/Amiga+CPLD/RAM_~W: U2.18; also elsewhere on the board
/Amiga+CPLD/R~W: CN1.62 (R~W), U2.54; also elsewhere on the board
/Amiga+CPLD/TCK: J1.4, U2.48 (TCK)
/Amiga+CPLD/TDI: J1.2, U2.45 (TDI)
/Amiga+CPLD/TDO: J1.3, U2.83 (TDO)
/Amiga+CPLD/TMS: J1.1, U2.47 (TMS)
/Amiga+CPLD/~AS: CN1.68 (~AS), U2.53
/Amiga+CPLD/~BERR: CN1.40 (~BERR), U2.70
/Amiga+CPLD/~CAS: U2.20; also elsewhere on the board
/Amiga+CPLD/~DTACK: CN1.60 (~DTACK), U2.56
/Amiga+CPLD/~EXTEN: U2.10, U11.1
/Amiga+CPLD/~FLASH_CE: U2.99 (I/O/GSR); also elsewhere on the board
/Amiga+CPLD/~FLASH_EN: RN1.1 (R1.1), SW1.4, U2.50
/Amiga+CPLD/~IDE_CS1: U2.4 (I/O/GTS2); also elsewhere on the board
/Amiga+CPLD/~IDE_CS2: U2.3 (I/O/GTS1); also elsewhere on the board
/Amiga+CPLD/~IDE_EN: RN1.2 (R2.1), SW1.3, U2.49
/Amiga+CPLD/~IDE_ROMCS: U2.1 (I/O/GTS3); also elsewhere on the board
/Amiga+CPLD/~IORD: U2.97; also elsewhere on the board
/Amiga+CPLD/~IOWR: U2.2 (I/O/GTS4); also elsewhere on the board
/Amiga+CPLD/~I_BUFOE: U2.7; also elsewhere on the board
/Amiga+CPLD/~LDS: CN1.64 (~LDS), U2.55
/Amiga+CPLD/~OVR: CN1.11 (~OVR), U2.94, U2.95
/Amiga+CPLD/~RAMCS: U2.24; also elsewhere on the board
/Amiga+CPLD/~RAM_EN: RN1.4 (R4.1), SW1.1, U2.43
/Amiga+CPLD/~RANGER_EN: RN1.3 (R3.1), SW1.2, U2.46
/Amiga+CPLD/~RAS: U2.22 (I/O/GCK1); also elsewhere on the board
/Amiga+CPLD/~RST: CN1.47 (~RST), U2.72; also elsewhere on the board
/Amiga+CPLD/~R_BUFOE: U2.16; also elsewhere on the board
/Amiga+CPLD/~UDS: CN1.66 (~UDS), U2.52
GND: C1.2, C2.2, C3.2, C4.2, C5.2, C6.2, C7.2, C8.2, C9.2, C10.2, C11.2, C27.2, C28.2, CN1.1 (GND), CN1.2 (GND), CN1.7 (GND), CN1.19 (GND), CN1.31 (GND), CN1.43 (GND), CN1.55 (GND), CN1.67 (GND), CN1.79 (GND), J1.5, J2.1, J3.1, R12.1, SW1.5, SW1.6, SW1.7, SW1.8, U1.1 (GND), U2.21 (GND), U2.31 (GND), U2.44 (GND), U2.62 (GND), U2.69 (GND), U2.75 (GND), U2.84 (GND), U2.100 (GND), U11.3 (GND), X1.2 (GND); also elsewhere on the board
unnamed: J2.2, R14.2
unnamed: J3.2, R13.2
unnamed: J5.1, J5.3, U11.4
unnamed: J5.2, R12.2, U11.2
unnamed: R1.1, X1.3 (OUT)
VCC: C2.1, C5.1, C27.1, C28.1, CN1.3 (VCC), CN1.4 (VCC), R2.1, R11.1, U1.3 (VI), U11.5 (VCC); also elsewhere on the board

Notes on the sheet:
JTAG

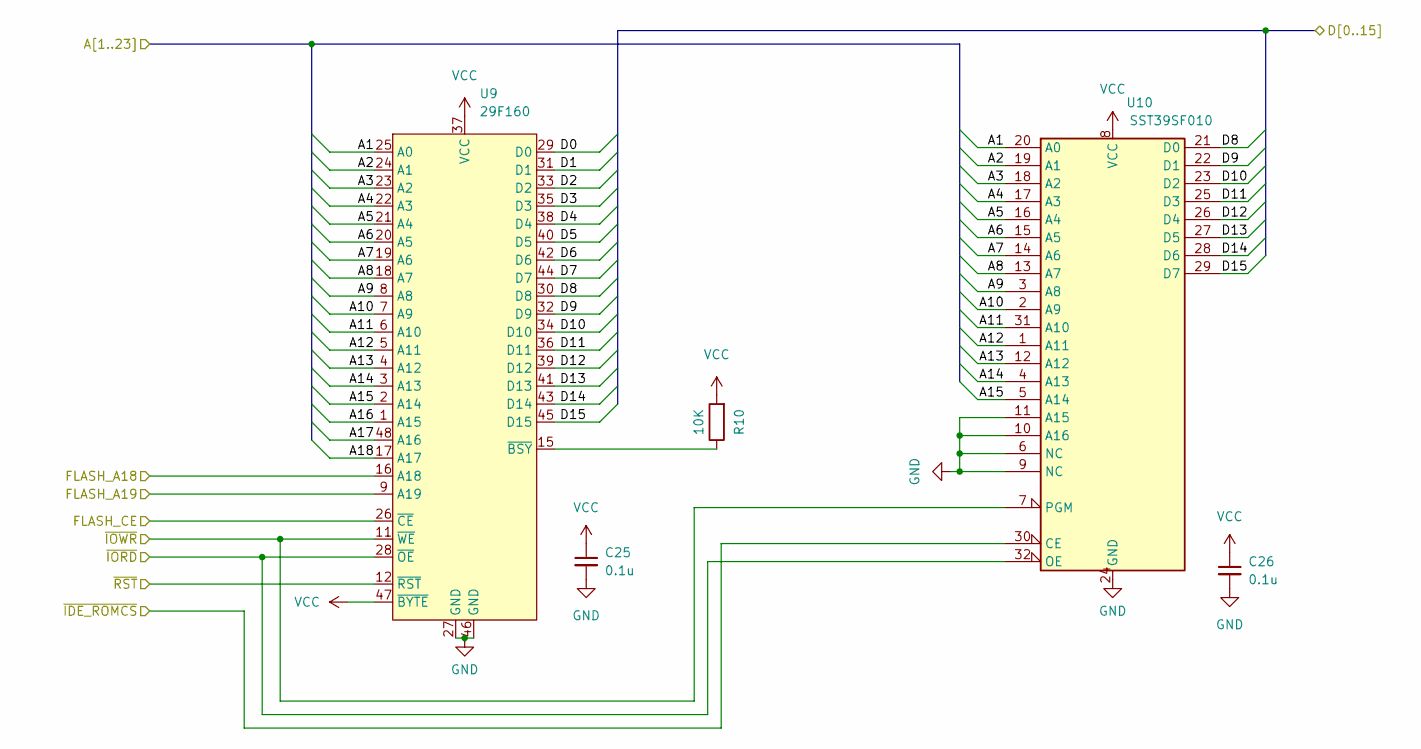
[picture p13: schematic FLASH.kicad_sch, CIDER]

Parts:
C25, C26: 0.1u; C_0603_1608Metric; LCSC # C14663
R10: 10K; R_0603_1608Metric; LCSC # C25804
U9: 29F160; TSOP-I-48_18.4x12mm_P0.5mm
U10: SST39SF010; TSOP-I-32_11.8x8mm_P0.5mm

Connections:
/Amiga+CPLD/A1: U9.25 (A0), U10.20 (A0); also elsewhere on the board
/Amiga+CPLD/A2: U9.24 (A1), U10.19 (A1); also elsewhere on the board
/Amiga+CPLD/A3: U9.23 (A2), U10.18 (A2); also elsewhere on the board
/Amiga+CPLD/A4: U9.22 (A3), U10.17 (A3); also elsewhere on the board
/Amiga+CPLD/A5: U9.21 (A4), U10.16 (A4); also elsewhere on the board
/Amiga+CPLD/A6: U9.20 (A5), U10.15 (A5); also elsewhere on the board
/Amiga+CPLD/A7: U9.19 (A6), U10.14 (A6); also elsewhere on the board
/Amiga+CPLD/A8: U9.18 (A7), U10.13 (A7); also elsewhere on the board
/Amiga+CPLD/A9: U9.8 (A8), U10.3 (A8); also elsewhere on the board
/Amiga+CPLD/A10: U9.7 (A9), U10.2 (A9); also elsewhere on the board
/Amiga+CPLD/A11: U9.6 (A10), U10.31 (A10); also elsewhere on the board
/Amiga+CPLD/A12: U9.5 (A11), U10.1 (A11); also elsewhere on the board
/Amiga+CPLD/A13: U9.4 (A12), U10.12 (A12); also elsewhere on the board
/Amiga+CPLD/A14: U9.3 (A13), U10.4 (A13); also elsewhere on the board
/Amiga+CPLD/A15: U9.2 (A14), U10.5 (A14); also elsewhere on the board
/Amiga+CPLD/A16: U9.1 (A15); also elsewhere on the board
/Amiga+CPLD/A17: U9.48 (A16); also elsewhere on the board
/Amiga+CPLD/A18: U9.17 (A17); also elsewhere on the board
/Amiga+CPLD/D0: U9.29 (D0); also elsewhere on the board
/Amiga+CPLD/D1: U9.31 (D1); also elsewhere on the board
/Amiga+CPLD/D2: U9.33 (D2); also elsewhere on the board
/Amiga+CPLD/D3: U9.35 (D3); also elsewhere on the board
/Amiga+CPLD/D4: U9.38 (D4); also elsewhere on the board
/Amiga+CPLD/D5: U9.40 (D5); also elsewhere on the board
/Amiga+CPLD/D6: U9.42 (D6); also elsewhere on the board
/Amiga+CPLD/D7: U9.44 (D7); also elsewhere on the board
/Amiga+CPLD/D8: U9.30 (D8), U10.21 (D0); also elsewhere on the board
/Amiga+CPLD/D9: U9.32 (D9), U10.22 (D1); also elsewhere on the board
/Amiga+CPLD/D10: U9.34 (D10), U10.23 (D2); also elsewhere on the board
/Amiga+CPLD/D11: U9.36 (D11), U10.25 (D3); also elsewhere on the board
/Amiga+CPLD/D12: U9.39 (D12), U10.26 (D4); also elsewhere on the board
/Amiga+CPLD/D13: U9.41 (D13), U10.27 (D5); also elsewhere on the board
/Amiga+CPLD/D14: U9.43 (D14), U10.28 (D6); also elsewhere on the board
/Amiga+CPLD/D15: U9.45 (D15), U10.29 (D7); also elsewhere on the board
/Amiga+CPLD/FLASH_A18: U9.16 (A18); also elsewhere on the board
/Amiga+CPLD/FLASH_A19: U9.9 (A19); also elsewhere on the board
/Amiga+CPLD/~FLASH_CE: U9.26 (~CE); also elsewhere on the board
/Amiga+CPLD/~IDE_ROMCS: U10.30 (CE); also elsewhere on the board
/Amiga+CPLD/~IORD: U9.28 (~OE), U10.32 (OE); also elsewhere on the board
/Amiga+CPLD/~IOWR: U9.11 (~WE), U10.7 (PGM); also elsewhere on the board
/Amiga+CPLD/~RST: U9.12 (~RST); also elsewhere on the board
GND: C25.2, C26.2, U9.27 (GND), U9.46 (GND), U10.6 (NC), U10.9 (NC), U10.10 (A16), U10.11 (A15), U10.24 (GND); also elsewhere on the board
unnamed: R10.1, U9.15 (~BSY)
VCC: C25.1, C26.1, R10.2, U9.37 (VCC), U9.47 (~BYTE), U10.8 (VCC); also elsewhere on the board

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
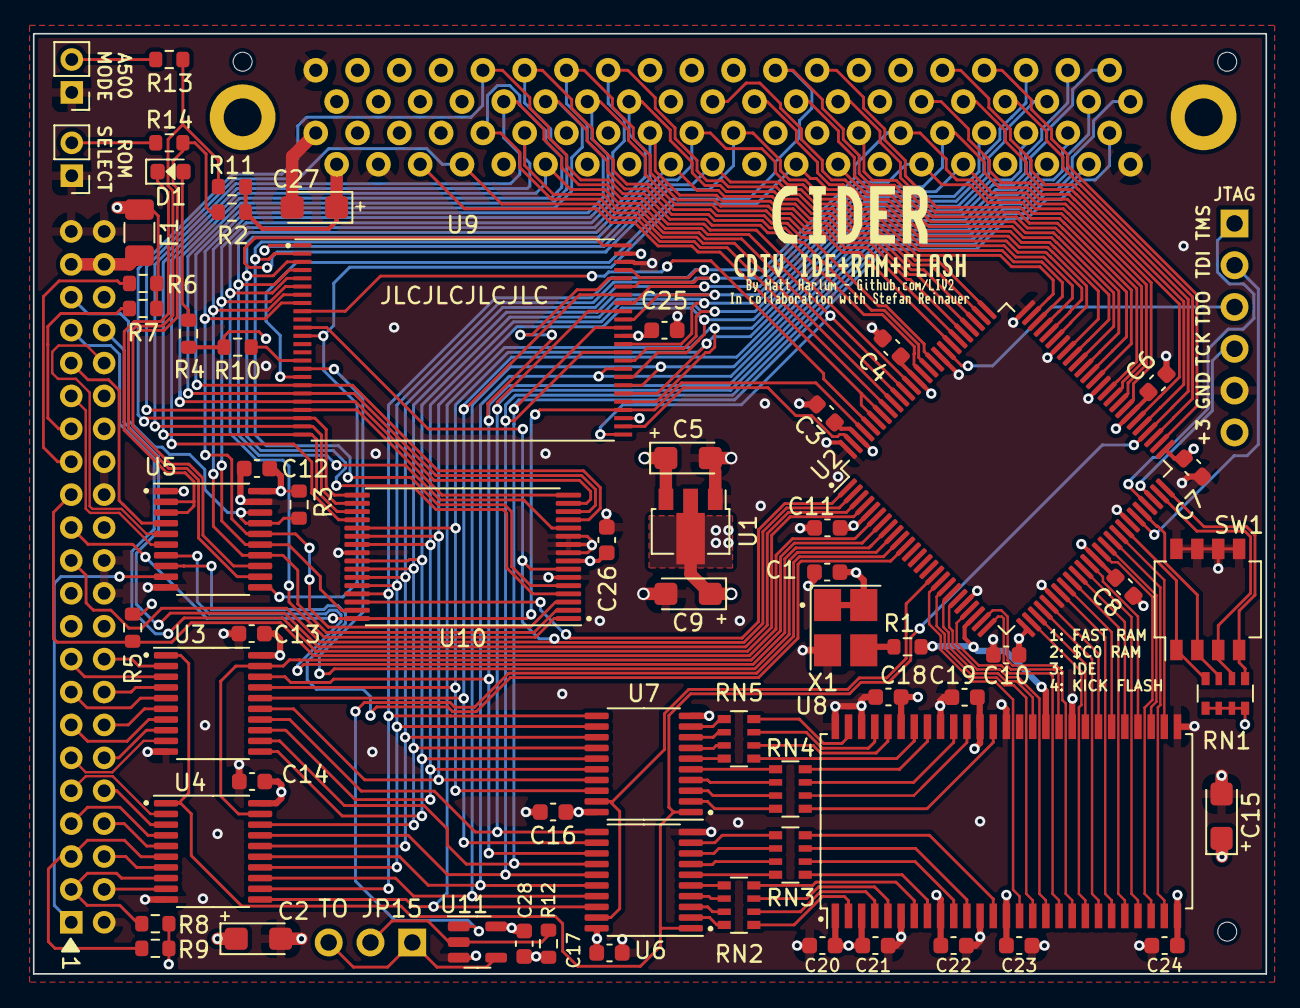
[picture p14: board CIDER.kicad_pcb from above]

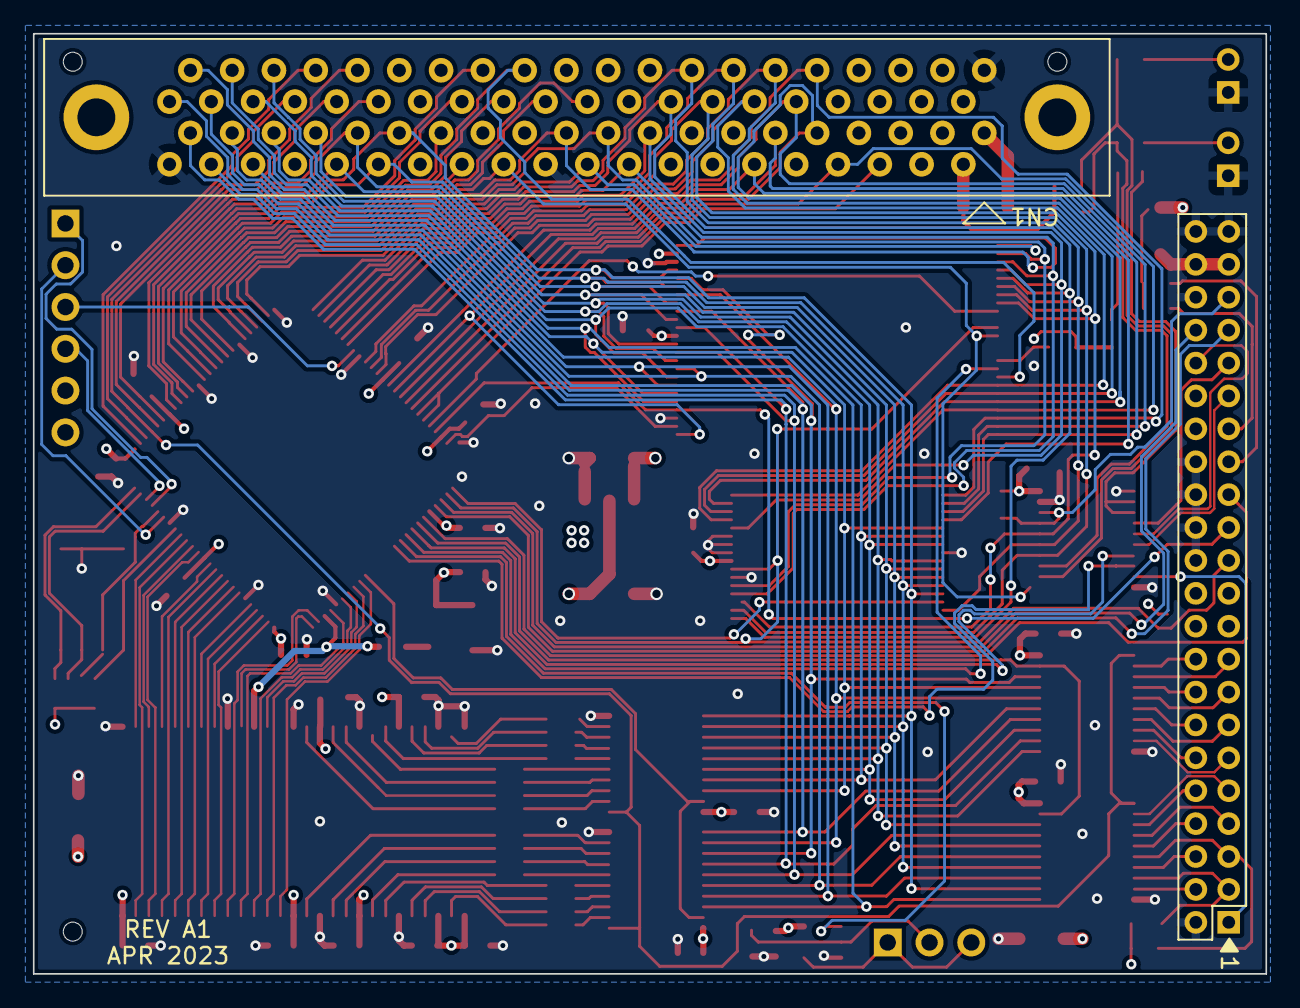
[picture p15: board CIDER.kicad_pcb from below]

Board: 4 copper layers, 74.9 x 57.1 mm, 72 parts (2 on the bottom side), 161 nets.

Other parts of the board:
kibuzzard-63D81BD7: G***; kibuzzard-63D81BD7
kibuzzard-63D81BF2: G***; kibuzzard-63D81BF2
kibuzzard-6443E00F: G***; kibuzzard-6443E00F
kibuzzard-6443E01A: G***; kibuzzard-6443E01A

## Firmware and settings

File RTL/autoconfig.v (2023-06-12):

/*
 * Copyright (C) 2023 Matthew Harlum <matt@harlum.net>
 *
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
 * You should have received a copy of the GNU General Public License
 * along with this program; if not, write to the Free Software Foundation,
 * Inc., 51 Franklin Street, Fifth Floor, Boston, MA 02110-1301, USA.
 */
module Autoconfig (
    input [23:1] ADDR,
    input AS_n,
    input CLK,
    input RW,
    input [3:0] DIN,
    input RESET_n,
    input RAM_EN,
    input RANGER_EN,
    input ext_en,
    input OTHER_EN,
    input maprom_en,
    input mapram_en,
    input ide_enabled,
    input OVL,
    input [1:0] z2_state,
    output ram_access,
    output ide_access,
    output ctrl_access,
    output flash_access,
    output autoconfig_cycle,
    output reg [3:0] DOUT,
    output reg dtack
);

`include "globalparams.vh"

`define maprom
`ifndef makedefines
`define PRODID 8'd72
`endif

// Autoconfig
localparam [15:0] mfg_id  = 16'd5194;
localparam [31:0] serial  = 32'd1;

reg ram_configured;
reg ide_configured;
reg ctl_configured;

reg [2:0] ide_base;
reg [3:0] ctrl_base;
reg cdtv_configured;
reg cfgin;
reg cfgout;

reg [1:0] ac_state;

localparam ac_ram  = 2'b00,
           ac_ctl  = 2'b01,
           ac_ide  = 2'b10,
           ac_done = 2'b11;

wire [7:0] prodid [0:2];
assign prodid[ac_ram] = 8'd4;
assign prodid[ac_ide] = 8'h5;
assign prodid[ac_ctl] = 8'd6;

wire [3:0] boardSize [0:2];
assign boardSize[ac_ram] = 4'b0000; // 8M
assign boardSize[ac_ide] = 4'b0010; // 128K
assign boardSize[ac_ctl] = 4'b0001; // 64K

assign autoconfig_cycle = (ADDR[23:16] == 8'hE8) && cfgin && !cfgout;

// CDTV DMAC is first in chain.
// So we wait until it's configured before we talk
always @(posedge CLK or negedge RESET_n) begin
  if (!RESET_n) begin
    cdtv_configured <= 0;
  end else begin
    if (ADDR[23:16] == 8'hE8 & ADDR[8:1] == 8'h24 & !AS_n & !RW) begin
      cdtv_configured <= 1'b1;
    end
  end
end

// These need to be registered at the end of a bus cycle
always @(posedge AS_n or negedge RESET_n) begin
  if (!RESET_n) begin
    cfgout <= 0;
    cfgin  <= 0;
  end else begin
    cfgin  <= cdtv_configured;
    cfgout <= (ac_state == ac_done);
  end
end

always @(posedge CLK or negedge RESET_n)
begin
  if (!RESET_n) begin
    DOUT           <= 'b0;
    ac_state       <= (RAM_EN) ? ac_ram : (ac_ram + 1);
    dtack          <= 0;
    ide_base       <= 3'b0;
    ctrl_base      <= 3'b0;
    ide_configured <= 0;
    ram_configured <= 0;
    ctl_configured <= 0;
  end else if (z2_state == Z2_DATA && autoconfig_cycle && !dtack) begin
    dtack <= 1;
    if (RW) begin
      case (ADDR[8:1])
        8'h00: 
          begin
            case (ac_state)
              ac_ram:  DOUT <= 4'b1110;                            // Memory / Link to free mem pool
              ac_ide:  DOUT <= {3'b110, ide_enabled};              // IO / Read from autoboot rom
              ac_ctl:  DOUT <= 4'b1100;                            // IO
            endcase
          end
        8'h01:   DOUT <= {boardSize[ac_state]};                    // Size: 8MB, 64K, 128K
        8'h02:   DOUT <= ~(prodid[ac_state][7:4]);                 // Product number
        8'h03:   DOUT <= ~(prodid[ac_state][3:0]);                 // Product number
        8'h04:   DOUT <= ~{ac_state == ac_ram ? 1 : 1'b0, 3'b000}; // Bit 1: Add to Z2 RAM space if set
        8'h05:   DOUT <= ~4'b0000;
        8'h08:   DOUT <= ~mfg_id[15:12];              // Manufacturer ID
        8'h09:   DOUT <= ~mfg_id[11:8];               // Manufacturer ID
        8'h0A:   DOUT <= ~mfg_id[7:4];                // Manufacturer ID
        8'h0B:   DOUT <= ~mfg_id[3:0];                // Manufacturer ID
        8'h0C:   DOUT <= ~serial[31:28];                           // Serial number
        8'h0D:   DOUT <= ~serial[27:24];                           // Serial number
        8'h0E:   DOUT <= ~serial[23:20];                           // Serial number
        8'h0F:   DOUT <= ~serial[19:16];                           // Serial number
        8'h10:   DOUT <= ~serial[15:12];                           // Serial number
        8'h11:   DOUT <= ~serial[11:8];                            // Serial number
        8'h12:   DOUT <= ~serial[7:4];                             // Serial number
        8'h13:   DOUT <= ~serial[3:0];                             // Serial number
        8'h14:   DOUT <= ~4'h0;                                    // ROM Offset high byte high nibble
        8'h15:   DOUT <= ~4'h0;                                    // ROM Offset high byte low nibble
        8'h16:   DOUT <= ~4'h0;                                    // ROM Offset low byte high nibble
        8'h17:   DOUT <= ~4'h8;                                    // ROM Offset low byte low nibble
        8'h20:   DOUT <= 4'b0;
        8'h21:   DOUT <= 4'b0;
        default: DOUT <= 4'hF;
      endcase
    end else begin
      if (ADDR[8:1] == 8'h26) begin
          // We've been told to shut up (not enough memory space)
          ac_state <= ac_state + 1;
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

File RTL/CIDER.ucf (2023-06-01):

NET "ADDR<1>"  LOC = "P90"  ;
NET "ADDR<10>"  LOC = "P82"  ;
NET "ADDR<11>"  LOC = "P77"  ;
NET "ADDR<12>"  LOC = "P78"  ;
NET "ADDR<13>"  LOC = "P80"  ;
NET "ADDR<14>"  LOC = "P79"  ;
NET "ADDR<15>"  LOC = "P74"  ;
NET "ADDR<16>"  LOC = "P76"  ;
NET "ADDR<17>"  LOC = "P73"  ;
NET "ADDR<18>"  LOC = "P66"  ;
NET "ADDR<19>"  LOC = "P67"  ;
NET "ADDR<2>"  LOC = "P91"  ;
NET "ADDR<20>"  LOC = "P63"  ;
NET "ADDR<21>"  LOC = "P64"  ;
NET "ADDR<22>"  LOC = "P68"  ;
NET "ADDR<23>"  LOC = "P65"  ;
NET "ADDR<3>"  LOC = "P89"  ;
NET "ADDR<4>"  LOC = "P87"  ;
NET "ADDR<5>"  LOC = "P93"  ;
NET "ADDR<6>"  LOC = "P92"  ;
NET "ADDR<7>"  LOC = "P85"  ;
NET "ADDR<8>"  LOC = "P86"  ;
NET "ADDR<9>"  LOC = "P81"  ;
NET "AS_n"  LOC = "P53"  ;
NET "BA<0>"  LOC = "P27"  ;
NET "BA<1>"  LOC = "P29"  ;
NET "BERR_n"  LOC = "P70"  ;
NET "CAS_n"  LOC = "P20"  ;
NET "CKE"  LOC = "P25"  ;
NET "DBUS<12>"  LOC = "P59"  ;
NET "DBUS<13>"  LOC = "P58"  ;
NET "DBUS<14>"  LOC = "P61"  ;
NET "DBUS<15>"  LOC = "P60"  ;
NET "DQMH"  LOC = "P19"  ;
NET "DQML"  LOC = "P17"  ;
NET "DTACK_n"  LOC = "P56"  ;
NET "ECLK"  LOC = "P71"  ;
NET "EXTEN_n"  LOC = "P10"  ;
NET "A500_n"   LOC = "P11"  ;
NET "FLASH_A18"  LOC = "P9"  ;
NET "FLASH_A19"  LOC = "P96"  ;
NET "FLASH_BANK_SEL_n"  LOC = "P8"  ;
NET "FLASH_CE_n"  LOC = "P99"  ;
NET "FLASH_EN_n"  LOC = "P50"  ;
NET "IDE_ROMEN"  LOC = "P1"  ;
NET "IDEBUF_OE"  LOC = "P7"  ;
NET "IDECS1_n"  LOC = "P4"  ;
NET "IDECS2_n"  LOC = "P3"  ;
NET "IDEEN_n"  LOC = "P49"  ;
NET "IOR_n"  LOC = "P97"  ;
NET "IORDY"  LOC = "P6"  ;
NET "IOW_n"  LOC = "P2"  ;
NET "LDS_n"  LOC = "P55"  ;
NET "MA<0>"  LOC = "P34"  ;
NET "MA<1>"  LOC = "P36"  ;
NET "MA<10>"  LOC = "P32"  ;
NET "MA<11>"  LOC = "P28"  ;
NET "MA<2>"  LOC = "P39"  ;
NET "MA<3>"  LOC = "P41"  ;
NET "MA<4>"  LOC = "P42"  ;
NET "MA<5>"  LOC = "P40"  ;
NET "MA<6>"  LOC = "P37"  ;
NET "MA<7>"  LOC = "P35"  ;
NET "MA<8>"  LOC = "P33"  ;
NET "MA<9>"  LOC = "P30"  ;
NET "MEMCLK"  BUFG = "CLK" ;
NET "MEMCLK"  LOC = "P23"  ;
NET "MEMW_n"  LOC = "P18"  ;
NET "OVR_1_n"  LOC = "P94"  ;
NET "OVR_2_n"  LOC = "P95"  ;
NET "RAM_EN_n"  LOC = "P43"  ;
NET "RAMCS_n"  LOC = "P24"  ;
NET "RAMOE_n"  LOC = "P16"  ;
NET "RANGER_EN_n"  LOC = "P46"  ;
NET "RAS_n"  LOC = "P22"  ;
NET "RESET_n"  LOC = "P72"  ;
NET "RW"  LOC = "P54"  ;
NET "UDS_n"  LOC = "P52"  ;

NET "MEMCLK" TNM_NET = MEMCLK;
TIMESPEC TS_CLK = PERIOD "MEMCLK" 50 MHz HIGH 50%;

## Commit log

2023-01-21 Initial commit.
    Start with the HDL, need to replace gayle IDE with Apollo IDE
    [SDRAM.v, autoconfig.v]
2023-01-22 Begin PCB design
    * Added footprint for KEL connector
    * Added symbol for CDTV Diag port
    * Initial schematic entry
    [CIDER.kicad_pcb, CIDER.kicad_sch, IDE.kicad_sch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]
2023-01-22 PCB: Add 39SF010 for IDE ROM
    [CIDER.kicad_sch, FLASH.kicad_sch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]
2023-01-22 PCB: Change IDE address line connections from A2-4 to A10-12 (Gayle vs AT-Apollo style IDE)
    [IDE.kicad_sch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]
2023-01-23 RTL: Continue implementation * Replace Gayle IDE Emulation with AT-Apollo style IDE * Rework Autoconfig module to also config IDE & Control register devices
    [SDRAM.v, autoconfig.v]
2023-01-28 PCB: Change IDE address line connections to A9-11 (AT-Bus style)
    [CIDER.kicad_sch, IDE.kicad_sch]
2023-01-28 PCB: Start routing PCB
    [Amiga-CPLD.kicad_sch, CIDER-B_Cu.gbl, CIDER-B_Mask.gbs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]
2023-01-28 PCB: Keep on routing...
    [Amiga-CPLD.kicad_sch, CIDER-B_Cu.gbl, CIDER-B_Mask.gbs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]
2023-01-29 PCB: More routing...
    [Amiga-CPLD.kicad_sch, CIDER-B_Cu.gbl, CIDER-B_Mask.gbs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]
2023-01-30 PCB: More work...
    * Add DIP Switches for Ram/Rom/IDE config
    * Route bank select signals for Flash rom
    * Flip IDE to bottom of the board
    * Add some bulk capacitors
    [Amiga-CPLD.kicad_sch, CIDER-B_Cu.gbl, CIDER-B_Mask.gbs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]
2023-01-30 PCB: Route Flash bank switch jumper
    [Amiga-CPLD.kicad_sch, CIDER-B_Cu.gbl, CIDER-B_Mask.gbs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]
2023-01-30 PCB: Add 22 Ohm series resistors for SDRAM
    [Amiga-CPLD.kicad_sch, CIDER-B_Cu.gbl, CIDER-B_Mask.gbs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]
2023-01-31 PCB: Connect Flash A18 to CPLD
    [Amiga-CPLD.kicad_sch, CIDER-B_Cu.gbl, CIDER-B_Mask.gbs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]
2023-02-03 RTL: Fix autoconfig
    The CDTV's diag port connects config_in/out to gnd making them useless.
    Wait until we see the DMAC get assigned it's address instead...
    While we're at it make the ram disable switch work
    [CIDER.ucf, autoconfig.v]
2023-02-03 PCB: Remove useless cfgin connection
    [Amiga-CPLD.kicad_sch, CIDER-B_Cu.gbl, CIDER-B_Mask.gbs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]
2023-02-03 PCB: Fixups
    * Tweak KEL connector hole sizes
    * Fixup MT48LC8M16A2P - Had copied this from the 16M16 part and forgot to make A12 an NC
    [Amiga-CPLD.kicad_sch, CIDER-B_Cu.gbl, CIDER-B_Mask.gbs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]
2023-02-04 CFLASH: couple of fixups
2023-02-05 PCB: Connect another CPLD pin to OVR_n
    This should give more drive strength to make sure we can drive it low nice and fast
    [Amiga-CPLD.kicad_sch, CIDER-B_Cu.gbl, CIDER-B_Mask.gbs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]
2023-02-06 RTL: Fixup ctrl_access equation
    [autoconfig.v]
2023-02-07 PCB: Connect NC's of 39SF010 to GND
    This will allow people to substitute 39SF020/040 if the 010 ever becomes unobtanium
    [CIDER-B_Cu.gbl, CIDER-B_Mask.gbs, CIDER-B_Paste.gbp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]
2023-02-07 Update PCB Render
2023-02-08 Add ground pours
    Apparently JLCPCB are now incapable of producing 4-layer PCBs with less than 30% copper on outer layers...
    [CIDER-B_Cu.gbl, CIDER-B_Mask.gbs, CIDER-B_Paste.gbp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]
2023-02-09 PCB: Fix drill/component grid & U10 missing from bom
    [CIDER-B_Cu.gbl, CIDER-B_Mask.gbs, CIDER-B_Paste.gbp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]
2023-02-19 RTL: Fixups
    * Expansion ignores rom vector if it is 0, set the offset to 8
    * Fixup IDE ROM - needs to be available for full 64K range
    * Change to BSC/AT-Bus Manuf/Prod id for IDE during testing
    * Fixup autoconfig goofs
    * IDE ROM goes away after first write to IDE space
    [autoconfig.v]
2023-02-19 cflash: Slots
    Describe top/bottom half as slots rather than banks to make usage more obvious
2023-02-19 RTL: Latch maprom enable at reset, disable autoboot rom flag when IDE disabled
    [autoconfig.v]
2023-02-20 Addram: fix merge behaviour
    Previously cd_BoardAddr pointed to the FastRAM board but this was changed to be the Control register
    This meant that it was looking for a memory region at the control register base
    Instead just look through the MemList to find a bordering Fast RAM chunk
2023-02-21 GH Actions: Build software & attach to release
2023-02-21 GH Actions: Generate kicad outputs
2023-02-24 iderom: rework as a chainloader module
    This way I can load a driver that uses RTF_AUTOINIT and then call mounter afterwards to add the boot entries
2023-04-25 Proto B
    Add connection to CDTV JP15 to disable extended rom decode when Flash ROM active
    [Amiga-CPLD.kicad_sch, CIDER-B_Cu.gbl, CIDER-B_Mask.gbs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]
2023-04-25 Proto_B: Add A500 mode switch
2023-04-25 Proto_B: Add A500 mode jumper, add SMD Act LED
    [Amiga-CPLD.kicad_sch, CIDER-B_Cu.gbl, CIDER-B_Mask.gbs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]
2023-04-25 Rev_A: Proto_B is now Rev A
    Also adds a 3D model for the KEL Connector (Thanks Eriond!)
    [CIDER.kicad_pcb]
2023-04-25 Rev_A: Generate outputs
    [CIDER-B_Cu.gbl, CIDER-B_Mask.gbs, CIDER-B_Paste.gbp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]
2023-04-25 Fixup some of the JLC part numbers
    [CIDER_bom_jlc.csv, RAM.kicad_sch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]
2023-04-30 Rev_A1: Add pull-down resistor for U11 input, add tooling holes
    [Amiga-CPLD.kicad_sch, CIDER-B_Cu.gbl, CIDER-B_Mask.gbs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]
2023-05-11 Rev_A: Fixup JLC Part # for Volt reg
    [CIDER.kicad_sch, CIDER_bom_jlc.csv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]
2023-05-11 Rev_A1: Fixup JLC Part # for Volt reg
    [CIDER.kicad_sch, CIDER_bom_jlc.csv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]
2023-05-13 Rev_A1: Invert polarity of A500 and FLASH_BANK_SEL inputs
    [CIDER.ucf]
2023-05-13 Rev-A1: Buffer A500/Bank Sel switches
    Added inline resistors to these two and buffer them via U5
    In Proto A it was found that operating the switches would cause latch-up and destroy the CPLD
    [Amiga-CPLD.kicad_sch, CIDER-B_Cu.gbl, CIDER-B_Mask.gbs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]
2023-05-13 Rev-A1: move switch headers to top of the board and update render
    [Amiga-CPLD.kicad_sch, CIDER-B_Cu.gbl, CIDER-B_Mask.gbs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]
2023-05-16 Fixup RAM product ID
    Was supposed to be Decimal not Hex
    [autoconfig.v]
2023-06-12 Switch to OAHR allocated Autoconfig IDs
2023-08-10 Firmware fixes
    * IDE IOR/IOW change timing to fix IDE corruption issues
    * DTACK timing fixup, SDRAM was unnecessarily holding off DTACK
    [SDRAM.v]
2023-08-26 Add Bill of materials with Mouser links
2023-08-26 Add photos
    [CIDER.kicad_pcb]

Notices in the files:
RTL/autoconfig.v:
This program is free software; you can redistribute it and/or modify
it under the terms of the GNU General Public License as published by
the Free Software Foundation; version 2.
